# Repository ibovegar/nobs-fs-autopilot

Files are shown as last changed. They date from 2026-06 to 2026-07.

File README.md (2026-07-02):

# Nobs Autopilot

A build-it-yourself control panel for flight simulators, with **4 rotary encoders** and **8 toggle
switches** wired to an **Arduino Nano ESP32** (an older **Arduino Micro** is also supported). It
plugs in over USB and shows up as a standard game controller (HID gamepad) named **"Nobs
Autopilot"**, recognised directly by MSFS or DCS and the Nobs app, with no drivers to install.

Each encoder's turn-left, turn-right, and push are reported as 3 buttons (12 total); the 8 toggle
switches add 8 more, for **20 buttons** total.

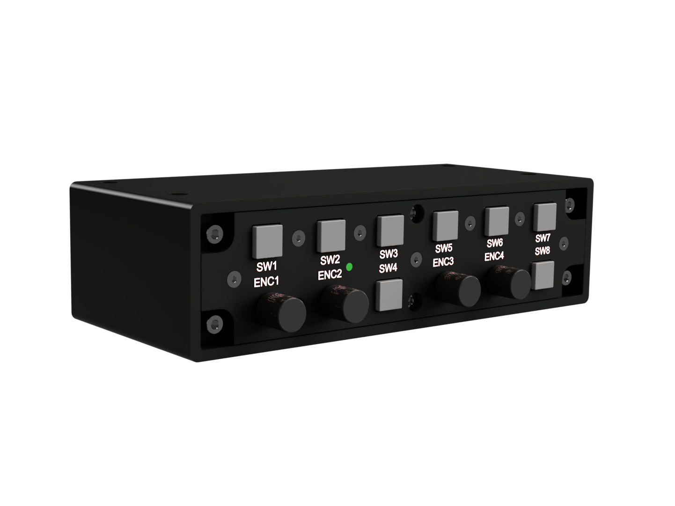
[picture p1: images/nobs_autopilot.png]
Nobs Autopilot


## Mounting

The Nobs panels are designed to mount to a 40x80 T-slot aluminium extrusion rig (e.g. a Track
Racer TR160), around the central profile assembly that holds the flight yoke or steering wheel:
**Nobs Panel** mounts to the left of the assembly, **Nobs Approach** to the right, and **Nobs
Autopilot** on top.

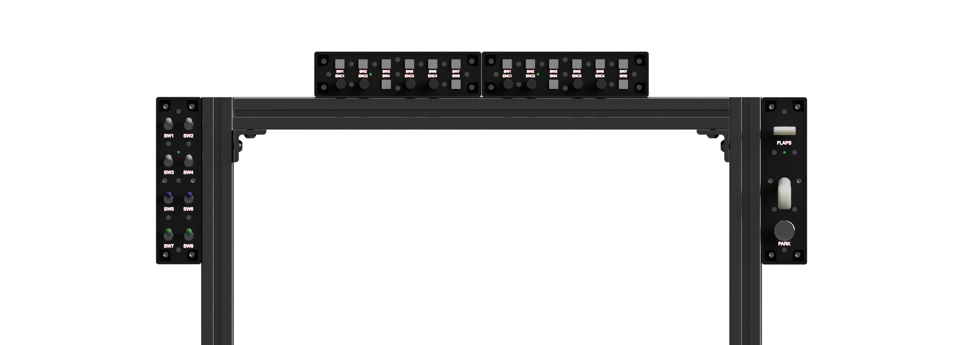
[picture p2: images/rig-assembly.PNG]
Rig assembly


## Virtual Reality (VR) Design Philosophy

Unlike traditional cockpit panels, **this project is engineered specifically for VR flight
simulator users**. Because you cannot see your physical hands while wearing a headset, this panel
discards all visual screens, LEDs, and digital displays. Instead, it focuses entirely on **tactile
memory and physical feedback**:
* **High-Tactile Feedback:** Built using premium mechanical rotary encoders with clear, distinct
  detents (clicks) and robust subminiature toggle switches that offer a sharp, reassuring snap when
  thrown.
* **Spatial Layout Optimization:** The generous spacing and deliberate physical grouping of
  components make it incredibly easy to find, identify, and operate different knobs and buttons
  purely by touch.

## Docs

- **[Build instructions](docs/build-instructions.md)**: wiring map, physical pinout reference,
  step-by-step assembly with photos, and first-time verification.
- **[Which wire goes where](docs/arduino-esp-32-wiring.md)**: the button + pin map for the Nano
  ESP32 build. For a visual reference alongside it, see the
  [wiring diagram](docs/wiring-diagram-esp32-nano.pdf).
- **[Loading the firmware](firmware/arduino_eps32_nano/README.md)**: first-time flashing and
  re-flashing, step by step.
- **[Setting the device ID & name](docs/board-identity.md)**: how the board names itself, how to
  rename it, and how to run several boxes at once.
- **[Bill of materials](docs/bill-of-materials.md)**: parts list and project cost estimate.

## Using an Arduino Micro instead of the Nano ESP32

This guide is written around the **Arduino Nano ESP32**, but the project still fully supports the
older **Arduino Micro**; it ends up as the same **"Nobs Autopilot"** device (`303A` / `80F4`) and
behaves identically in the sim, except its name/ID are fixed at compile time instead of
reconfigurable (see [docs/board-identity.md](docs/board-identity.md)). If you go with the Micro,
two things differ:

1. **Wiring pins:** use [docs/arduino-micro-wiring.md](docs/arduino-micro-wiring.md) instead of
   the Nano ESP32 pin table in the [build instructions](docs/build-instructions.md), with its own
   [wiring diagram](docs/wiring-diagram-micro.pdf).
2. **Loading the firmware:** follow
   [firmware/arduino_micro/README.md](firmware/arduino_micro/README.md) instead (it needs a
   one-time `boards.txt` edit to set the board's USB name/ID before the first upload).

Everything else is unchanged: the parts list (just swap the board), the 3D-printed enclosure, the
assembly steps, the Nobs app, and the in-sim binding.

## Nobs FS Companion App

The [**Nobs FS app**](https://github.com/ibovegar/nobs-fs-app) is the companion application for
communicating with and configuring this panel. It automatically detects the Nobs Autopilot by its
USB identity (VID `303A` / PID `80F4`), so the right device is selected even when other game
controllers are connected.

Use it to:
* **Verify wiring & test inputs:** watch every encoder rotation, encoder push, and switch register
  live as you turn or press each control, handy for confirming the build before binding anything in
  the sim.
* **Configure the encoders:** the Settings page sets each encoder's acceleration sensitivity over
  the USB serial (CDC) port. The value is persisted to the Arduino's EEPROM, so it survives power
  cycles and applies in the sim too, no re-flashing required.

See the app repository for installation and usage details: <https://github.com/ibovegar/nobs-fs-app>

## Setting the device ID & name (in brief)

The board's name and USB product ID aren't compiled in: they're stored on the board (Nano ESP32
build only), so the same firmware can be set up as any Nobs profile. Out of the box this is
**"Nobs Autopilot"** (`303A` / `80F4`). To change it, the configuration app sends a single line
over the board's serial port:

```
SET_ID:80F4:Nobs Autopilot
```

The board saves the new name + ID, replies `OK:80F4:Nobs Autopilot`, and reboots so it takes effect
(`GET_ID` reads back the current values). For multiple autopilots, give each one the next ID in the
block, e.g. `SET_ID:80F5:Nobs Autopilot 2`. Full details, including the Windows name-cache
refresh, are in **[docs/board-identity.md](docs/board-identity.md)**.

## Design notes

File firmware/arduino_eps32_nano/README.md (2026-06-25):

# Nobs Autopilot: Arduino Nano ESP32 Firmware

> **Which board do you have?** This page is for the **Arduino Nano ESP32**, the main board for
> this project. If you're using the older **Arduino Micro** instead, follow
> [the Arduino Micro guide](../arduino_micro/README.md).

This is the program (the "firmware") that runs on an **Arduino Nano ESP32** board and turns it
into a USB game controller for Microsoft Flight Simulator. Once it's loaded, the board shows up
to your PC and to the Nobs app as **"Nobs Autopilot"** with **20 buttons**:

| Buttons | What they are |
| :--- | :--- |
| 12 buttons | 4 rotary knobs (each gives: turn left, turn right, press) |
| 8 buttons | 8 toggle switches |

You don't need to understand any of that to load it; just follow the steps below. If you're
curious how it works, there's a [How it works](#how-it-works-optional-reading) section at the end.

**Files you'll use** (they're all in this folder):
- The firmware: [`arduino_eps32_nano.ino`](./arduino_eps32_nano.ino)
- A small settings file next to it: [`build_opt.h`](./build_opt.h) *(leave it where it is, it's important)*
- Which wire goes where: [`docs/arduino-esp-32-wiring.md`](../../docs/arduino-esp-32-wiring.md)

> 👍 Good news: everything needed is already in this project folder. You do **not** have to edit
> any Arduino program files. Tested with the Arduino ESP32 board package version `2.0.18-arduino.5`.

## What you need

- An **Arduino Nano ESP32** board and a USB cable.
- The **Arduino IDE** installed (the free app from arduino.cc).
- This project downloaded to your computer.

## Step 1: Add support for the board

The Arduino IDE doesn't know about the Nano ESP32 until you add it:

1. In the Arduino IDE, open **Tools → Board → Boards Manager…**
2. In the search box type **Arduino ESP32 Boards** and click **Install** on the result by *Arduino*.
   This is a big download, so give it a few minutes.
3. When it's done, go to **Tools → Board → Arduino ESP32 Boards → Arduino Nano ESP32**.

> **If the install fails** with a message like *"platform not installed"*: close the Arduino IDE,
> right-click it and choose **Run as administrator**, then try the install again. (Windows needs
> the extra permission to set up the USB drivers.)

## Step 2: Pick the right settings

In the **Tools** menu, set:

- **USB Mode** → **`Normal mode (TinyUSB)`** (this is usually the default). Don't pick "Debug
  mode (Hardware CDC)".
- **Pin Numbering** → **`By Arduino pin (default)`** so the wiring diagram matches.

That's it; no other settings to change.

## Step 3: Load the firmware onto the board

1. Open `arduino_eps32_nano.ino` (in this folder) in the Arduino IDE.
   *(Keep the `build_opt.h` file in the same folder; the IDE uses it automatically.)*
2. Plug in the board.
3. Click the **Upload** button (the round arrow, top-left).

The **first** time, this just works. 🎉 When it's done, the board reconnects as **Nobs Autopilot**
and you can use it in the app.

> The board's name and product ID aren't baked into the firmware: they're stored on the board and
> can be changed later by the configuration app (see [Changing the board's
> identity](#changing-the-boards-identity-advanced)). Out of the box it's **"Nobs Autopilot"**.

## Loading it again later (please read, it's different!)

After the firmware is on the board, the board changes its "name tag" to Nobs Autopilot. The
Arduino IDE looks for the *original* Arduino name tag when uploading, so a normal Upload will now
**fail** with a red error like:

```
No DFU capable USB device available
Failed uploading: uploading error: exit status 74
```

This is normal and expected; it just means you need to put the board into its **update mode**
first. Here's how:

1. Find the small **RESET** button on the board.
2. **Press it twice, quickly**, like a fast mouse double-click.
3. Watch the lights: the **yellow/amber light goes off**, and a **green light slowly pulses in
   and out**. That pulsing green light means the board is now waiting for an update. 👍
4. **Now click Upload** in the Arduino IDE. It will load the firmware.
5. When it finishes, **press RESET once** (a single press) to start the new firmware. The
   yellow light comes back on.

> The double-tap takes a little practice: press, then press again within about half a second.
> If the yellow light stays on, it didn't work; just try the rhythm again. You can't break the
> board by doing this.

### If the double-tap won't cooperate (optional, more advanced)

You can load the firmware from the command line instead, which avoids the timing dance. Open
**PowerShell** in the project folder and run:

```powershell
# 1) Build the firmware once (find arduino-cli.exe inside your Arduino IDE install folder):
& "<path to your Arduino IDE>\resources\app\lib\backend\resources\arduino-cli.exe" `
  compile -b arduino:esp32:nano_nora --output-dir .\out firmware\arduino_eps32_nano

# 2) Double-tap RESET so the green light is pulsing, then run:
& "$env:LOCALAPPDATA\Arduino15\packages\arduino\tools\dfu-util\0.11.0-arduino5\dfu-util.exe" `
  --device 0x2341:0x0070 -D .\out\arduino_eps32_nano.ino.bin -Q

# 3) Press RESET once to start the firmware.
```

It worked if you see `Download done.` and `Done!` at the end.

## Checking that it works

- **Windows "game controllers" tool:** press `Win`, type **Set up USB game controllers**, open
  it, select the device, click **Properties**, and wiggle your knobs/switches; you should see
  the 20 buttons light up.
- **The Nobs app:** the controller is picked automatically, and the Settings page can connect to
  it.

### Finding it in Windows Device Manager

If you go looking in **Device Manager** and can't find "Nobs Autopilot", don't worry: it's
there, just listed in a confusing way by default. The easy fix:

> In Device Manager, click the **View** menu → **Devices by container**. Now the board shows up
> as a single entry named **Nobs Autopilot**. ✅

## Changing the board's identity (advanced)

Every Nobs box needs its own **product ID (PID)** and name so MSFS keeps their button bindings
separate. This board uses vendor ID `303A` and defaults to PID `80F4` / name **"Nobs Autopilot"**,
but those aren't compiled in. They're stored on the board and can be changed without re-flashing,
which is how the same firmware can be set up as any Nobs profile.

The configuration app does this for you over the board's COM port by sending a single line:

```
SET_ID:80F4:Nobs Autopilot
```

(`80F4` is the PID in hex; the text after it is the name.) The board saves the new values to its
internal memory, replies `OK:80F4:Nobs Autopilot`, and then **reboots itself** so the new identity
takes effect. Send `GET_ID` to read back what's currently stored (it replies `ID:80F4:Nobs Autopilot`).

Each product owns a **block of PIDs** so you can run several of the same type: each physical unit
takes the next PID in the block and a numbered name (module 1 keeps the bare name and the block's
first PID, its default):

| Profile | Vendor ID | PID block | Module 1 command |
| :--- | :--- | :--- | :--- |
| Nobs Panel | `303A` | `80F0`–`80F3` | `SET_ID:80F0:Nobs Panel` |
| Nobs Autopilot | `303A` | `80F4`–`80F7` | `SET_ID:80F4:Nobs Autopilot` |
| Nobs Approach | `303A` | `80F8`–`80FB` | `SET_ID:80F8:Nobs Approach` |

So a second autopilot would be `SET_ID:80F5:Nobs Autopilot 2`, a third `SET_ID:80F6:Nobs Autopilot 3`,
and so on.

> After changing the name, if Windows still shows the old one in **Game Controllers** or MSFS,
> force a refresh: in **Device Manager → Human Interface Devices**, right-click the controller →
> **Uninstall device**, then unplug the USB cable, wait ~2 seconds, and plug it back in. Windows
> re-reads the name fresh.

(In the normal view, one USB gadget like this gets split into a few separate generic-looking
entries (a "game controller", a "COM port", and a "USB Composite Device"), which is why it can
look like it's missing.)

## If something goes wrong

| What you see | What it means | What to do |
| :--- | :--- | :--- |
| *"Platform 'arduino:esp32' not found"* | The board support isn't installed | Do Step 1 again. On Windows, run the IDE **as administrator** if it fails partway. |
| Upload fails: *"No DFU capable USB device available"* or *"exit status 74"* | The board isn't in update mode | Double-tap RESET (wait for the pulsing green light), **then** Upload. See [Loading it again later](#loading-it-again-later-please-read-its-different). |
| Double-tap doesn't seem to do anything | Tricky timing, or you saw the normal 1-second light show at startup | You're in update mode only when the **yellow light is OFF** and the **green light keeps pulsing**. Keep trying the double-press. |
| The app or Windows shows it as **"Unknown device"** | Windows remembered an old, blank name | In Device Manager: **View → Show hidden devices**, right-click the board → **Uninstall device**, then unplug and replug it. |
| A long list of red *"No such file or directory"* errors when compiling | Someone added comments to `build_opt.h` | The `build_opt.h` file must contain **only** the settings line, no `//` comment lines. |

## Things that look wrong but are totally fine

- **A yellow light on the board stays on.** That's normal here: one of the knob wires shares the
  board's built-in LED pin, so the light is on whenever the firmware runs. If it bothers you, you
  can move that one wire to pin **D2** or **D4** and update the firmware + wiring diagram to match.

## How it works (optional reading)

You can skip this; it's just for the curious or for anyone maintaining the project.

### Why uploading needs the extra steps

A USB device tells your PC who it is using two ID numbers (called **VID** and **PID**) plus a
name. This board uses vendor ID `303A` and, by default, PID `80F4` / "Nobs Autopilot" so the Nobs
app recognises it. The PID and name aren't compiled in: the firmware reads them from the board's
internal memory at startup, which is what lets the [configuration
app](#changing-the-boards-identity-advanced) reassign the board to a different Nobs profile.

The tricky part: the Nano ESP32 normally locks in its ID numbers the instant it powers on,
*before* our firmware gets a chance to run, and it also hard-codes the "wrong" ID. So we use a
tiny helper file, **`build_opt.h`**, that sits next to the firmware. The Arduino IDE
automatically applies the settings in that file when it builds, which tells the board *not* to
start USB at power-on. That gives our firmware the opening it needs to read the stored ID/name
and set the right identity, buttons, and serial port itself, the moment it starts. (There's also
a built-in safety check that refuses to build if `build_opt.h` ever goes missing, so the board
can never quietly get the wrong ID.)

Because the board now reports the *custom* ID, the Arduino IDE's normal "auto-restart for
upload" can't find it, which is exactly why re-uploads need the manual double-tap into update
mode.

### What the firmware actually does

- Presents itself as a 20-button game controller (no joysticks/axes).
- Reads the 4 rotary knobs with proper quadrature decoding, and turns each "click" of the knob
  into a quick button press so even fast spinning is counted correctly in MSFS. Each knob also
  has adjustable acceleration (turn faster = bigger jumps), saved on the board.
- Provides a serial port so the Nobs app's Settings page can tweak that acceleration, and so the
  configuration app can change the board's USB ID/name (see [Changing the board's
  identity](#changing-the-boards-identity-advanced)).
- Reads the 8 switches as plain buttons.

The exact pin-to-wire mapping is in the [wiring diagram](../../docs/arduino-esp-32-wiring.md).

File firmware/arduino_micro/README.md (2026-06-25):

# Nobs Autopilot: Arduino Micro Firmware

This is the program (the "firmware") that runs on an **Arduino Micro** board and turns it into a
USB game controller for your flight sim. Once it's loaded, the board shows up to your PC and to
the Nobs app as **"Nobs Autopilot"** with 20 buttons (4 knobs + 8 switches).

> **Which board do you have?** This page is for the **Arduino Micro**, an alternative to the
> project's main board. If you're using the **Arduino Nano ESP32**, follow
> [the Nano ESP32 guide](../arduino_eps32_nano/README.md) instead. Note: only the Nano ESP32 build
> can have its name/ID changed later by the configuration app. On the Micro the USB ID is fixed
> when you build it (set in Step 1 below).

For the board to show up as "Nobs Autopilot" (and be picked up automatically by the Nobs app),
it needs to report a specific **USB ID**: two numbers the PC uses to recognise it (`303A` and
`80F4`). There's a one-time setup to make that happen, then loading the firmware is easy.

## Step 1: One-time setup to give the board its name

This step tells the Arduino IDE to build the firmware with the right name and USB ID. You only
have to do this **once** on your computer.

1. **Close the Arduino IDE completely.**
2. Open File Explorer, click the address bar, paste this in, and press Enter:
   ```
   %LOCALAPPDATA%\Arduino15\packages\arduino\hardware\avr\
   ```
3. Open the folder you see there (a version number, e.g. `1.8.6`).
4. Open the file **`boards.txt`** with Notepad.
5. Press `Ctrl+F`, search for **`micro.name`** (it's around line 290), and replace those few
   lines with this:
   ```
   micro.name=Nobs Autopilot
   micro.build.vid=0x303A
   micro.build.pid=0x80F4
   micro.build.usb_product="Nobs Autopilot"
   ```
6. **Save** the file and reopen the Arduino IDE.

> This only changes your own computer's Arduino setup. It doesn't change the project files, and
> anyone you give a finished, already-flashed board to doesn't need to do any of this.

## Step 2: Load the firmware

1. Open `arduino_micro.ino` (in this folder) in the Arduino IDE.
2. Go to **Tools → Board** and select **Nobs Autopilot** (that's the Arduino Micro; it shows the
   new name now because of Step 1).
3. Plug in the board and click **Upload** (the round arrow).

That's it.

## Check that it worked

Once connected, the board should introduce itself to your PC as:

```
Nobs Autopilot (Vendor: 303a Product: 80f4)
```

The Nobs app looks for exactly that USB ID (`303a` / `80f4`), so it automatically picks the right
controller even if you have other game controllers plugged in.

> **Seeing a generic name instead?** Open Windows **Device Manager**, turn on **View → Show
> hidden devices**, right-click any old/stale listing for the board and **Uninstall device**,
> then unplug and replug it so Windows reads the new name fresh.

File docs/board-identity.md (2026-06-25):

# How the Board Names Itself (and How to Rename It)

This page explains, in plain language, how a Nobs board tells your PC who it is, and how you can
change that without re-installing the firmware. You don't need to understand any of this to use the
autopilot; it's here for the curious and for anyone setting up more than one box.

> **Applies to the Arduino Nano ESP32 build.** On the older **Arduino Micro** build the ID and name
> are fixed when you compile the firmware (set in its
> [README](../firmware/arduino_micro/README.md)) and can't be changed afterwards. Everything below,
> including renaming on the fly and running several of the same type, is a Nano ESP32 feature.

## The short version

- Every Nobs box appears to your PC as a USB game controller with a **name** (like "Nobs Autopilot")
  and an **ID number** (called a *Product ID*, or **PID**).
- That name and ID are **not baked into the firmware**. The board remembers them in its own memory,
  so the *same* firmware can be set up as a panel, an autopilot, or an approach box.
- Out of the box, this board is **"Nobs Autopilot"**. You can change it later with the configuration
  app, no re-flashing needed.

## Why each box needs its own name and ID

If you own more than one Nobs box, this matters. Microsoft Flight Simulator keeps a separate set of
button bindings for each controller, but it tells controllers apart by their **ID number**.

If two boxes shared the same ID, the simulator would treat them as the same device and **mix up
their button assignments**. Giving each box its own ID (and a clear name) keeps their controls
neatly separated, so plugging in a second or third box never disturbs the first.

Here are the standard profiles. Each product owns a small **block of IDs** so you can have several
of the same type (see below):

| If the box is a… | It should be named… | ID block |
| :--- | :--- | :--- |
| Panel | Nobs Panel | `80F0`–`80F3` |
| Autopilot | Nobs Autopilot | `80F4`–`80F7` |
| Approach | Nobs Approach | `80F8`–`80FB` |

(They all share the same *vendor* ID, `303A`; that part never changes.)

## Running several of the same type

You can use more than one of the same module (say two autopilots) at the same time. The catch is
they must **not** look identical to the PC, or the simulator mixes up their bindings. So each one
gets its own ID and name from its product's block:

| | Name | ID |
| :-- | :-- | :-- |
| 1st autopilot | Nobs Autopilot | `80F4` |
| 2nd autopilot | Nobs Autopilot 2 | `80F5` |
| 3rd autopilot | Nobs Autopilot 3 | `80F6` |

The first one keeps the plain name and the block's first ID (its out-of-box default). For each
extra one, give it the next ID and a numbered name with the rename step below, e.g. send
`SET_ID:80F5:Nobs Autopilot 2` to the second autopilot. In the Nobs app, open **Devices** and press
**+** on that product to start tracking the extra module. The simulator then sees "Nobs Autopilot"
and "Nobs Autopilot 2" as two separate controllers with independent bindings.

## How to rename a board

The configuration app does this for you. Behind the scenes it just sends the board one short line of
text over its connection, for example:

```
SET_ID:80F4:Nobs Autopilot
```

That reads as: *"Set your ID to `80F4` and your name to `Nobs Autopilot`."* The board then:

1. **Saves** the new name and ID into its own memory.
2. **Confirms** it received them.
3. **Restarts itself**, then comes back wearing the new name.

That restart is normal and only takes a second. The reason it's needed: a board can only announce
its identity to the PC at the moment it powers on, so it has to reboot for a new name to take effect.

> 💡 To check what a board is currently called, the app can ask it with `GET_ID`, and the board
> replies with its stored name and ID.

## If Windows still shows the old name

Windows likes to remember names, so occasionally after a rename it'll keep showing the **old** one
in its game-controller list or in the simulator. If that happens, nudge it to take a fresh look:

1. Leave the board plugged in.
2. Right-click the **Start** button → open **Device Manager**.
3. Open the **Human Interface Devices** group.
4. Right-click your controller → **Uninstall device**.
5. Unplug the USB cable, wait a couple of seconds, and plug it back in.

Windows will then read the board's name again from scratch and show the updated one.

## Related pages

- [Which wire goes where](./arduino-esp-32-wiring.md): the button and pin map.
- [Loading the firmware](../firmware/arduino_eps32_nano/README.md): step-by-step setup, including
  the more technical details of how the identity is stored.

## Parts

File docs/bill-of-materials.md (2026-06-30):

# Bill of Materials (Shopping List)

This is the full shopping list for building one Nobs Autopilot panel: every part you need, from
the electronics to the screws. The tables below group the parts by type. The "Manufacturer /
Part Number" column lists the exact parts we used, so you can search for them or find equivalents.

A few friendly notes before you start buying:

- **Exact parts aren't mandatory.** The encoders, switches, and Arduino can be swapped for similar
  parts you like or already have. The part numbers here are just what's known to work.
- **Item 1.1 below is the Arduino Nano ESP32, the main board for this project.** You can use an
  older **Arduino Micro** instead; the firmware supports both. See the
  [firmware guides](../firmware/arduino_micro/README.md).
- **The enclosure parts (section 3) are 3D printed**: you print them yourself from the files in
  the `models/` folder, or have a print service make them.
- Quantities are for **one** panel.

## Core Electronics & Switches

| Item # | Qty | Component Description | Manufacturer / Part Number | Purpose / Application |
| :--- | :--- | :--- | :--- | :--- |
| **1.1** | 1 | Arduino Nano ESP32 (with headers) | Arduino / ABX00083 | Main microcontroller (ESP32-S3, USB HID, VID 0x303A / PID 0x80F4); or substitute an Arduino Micro (Arduino / A000053) |
| **1.2** | 4 | High-Reliability Mechanical Rotary Encoder | Bourns / PEC11H-4020F-S0016 | Multi-turn cockpit adjustments (HDG, ALT, V/S, SPD) |
| **1.3** | 8 | Subminiature SPDT Momentary Toggle Switch | E-Switch / 700SP7B10M2REH | Panel engagement buttons (SW1–SW8) |
| **1.4** | 1 | Stripboard Prototype Board | BusBoard Prototype Systems / StripBoard-1 | Main sub-assembly chassis carrier board |
| **1.5** | 2 | Female 2.54 mm Pin Header, 26 positions | — | Sockets soldered to the stripboard to seat the Arduino board (Nano ESP32 or Micro) |
| **1.6** | 8 | Fixed Terminal Block (2.54 mm Pitch) | GCT / TBC05-06-1-G-G | Clean screw-down wiring for switches and encoders |
| **1.7** | 1 | 3 mm Green Diffused LED | Lumex / SSL-LX30FT4GD | Power/status indicator |
| **1.8** | 1 | 120 Ω Metal Film Resistor, 1/4 W, ±1% | KOA Speer / MFS1/4DCT52R1200F | Current-limiting resistor for the indicator LED |

## Knobs, Caps, Connectors & Wiring

| Item # | Qty | Component Description | Specifications / Notes | Purpose / Application |
| :--- | :--- | :--- | :--- | :--- |
| **2.1** | 4 | Rotary Encoder Knob, 14 × 14.5 mm | Same Sky / SAK-023 | Physical interface dials for the 4 rotary encoders |
| **2.2** | 8 | Button Cap | C&K / 798209000 | Caps for the 700-series momentary switches |
| **2.3** | 1 | USB-C to USB-A Cable | 1.5 m to 2 m, data-sync capable | Connects the Arduino Nano ESP32 to your PC flight simulator setup (use USB Micro-B instead if building with the Arduino Micro) |
| **2.4** | 1 | 24 AWG Solid Core Hook-Up Wire Kit | Multi-color pack (black, red, blue, yellow) | Internal point-to-point wiring (signals and ground loops) |
| **2.5** | 1 | Heat Shrink Tubing Assortment Pack | 1.5 mm to 3.5 mm diameters | Insulates soldered connections on the encoder and switch lugs |

## Structural & Enclosure Hardware

| Item # | Qty | Component Description | Specifications / Notes | Purpose / Application |
| :--- | :--- | :--- | :--- | :--- |
| **3.1** | 1 | Enclosure Top | 3D Printed (PLA/PETG) | Main upper housing body shell |
| **3.2** | 1 | Enclosure Bottom | 3D Printed (PLA/PETG) | Main lower housing base structure |
| **3.3** | 1 | Mounting Plate | 3D Printed (PLA/PETG) | Interface bracket to attach the panel to your desk/rig |
| **3.4** | 1 | Front Plate | 3D Printed (PLA/PETG) | Visual faceplate holding switches and text labels |
| **3.5** | 13 | M3 Heat-Set Insert | Brass, press-fit | Threaded anchors moulded into the 3D-printed parts |
| **3.6** | 10 | M4 Heat-Set Insert | Brass, press-fit | Threaded anchors moulded into the 3D-printed parts |
| **3.7** | 9 | M3 × 10 mm Countersunk Screw | Flat head machine screws | Fastens the front plate flat against the enclosure frame |
| **3.8** | 4 | M3 × 6 mm Pan-Head Screw | Rounded button head | Fastens the internal circuit board assembly to its mounts |
| **3.9** | 6 | M4 × 6 mm Socket-Head Screw | Hex drive cap screws | Fastens the mounting plate interface to the enclosure body |
| **3.10** | 4 | M4 × 26 mm Socket-Head Screw | Hex drive long cap screws | Clamps the enclosure top and bottom halves together |

## Tools Recommended for Assembly (Not in BOM Cost)
* **Soldering Iron & Lead-Free Rosin-Core Solder:** Essential for attaching wires to the E-Switch gold terminals and Bourns pins.
* **Wire Strippers & Flush Cutters:** For clean trimming and prepping of your 24 AWG signal cables.
* **Soldering Iron / Insert Tool for Heat-Set Inserts:** For pressing the brass inserts squarely into the 3D-printed parts.
* **Multimeter:** Crucial for testing continuity and checking for short circuits across your common ground loops before plugging into USB power.

## Project Costs

Rough cost estimate for a single panel, in USD. These are ballpark figures only, actual prices vary significantly by supplier, region, and quantity, and **exclude shipping and taxes**. Several items (wire, heat-shrink, screws, inserts) are sold in multi-build packs, so the per-build cost is lower if you build more than one or already have them on hand.

| Category | Items | Estimated Cost |
| :--- | :--- | ---: |
| Microcontroller | Arduino Nano ESP32 (genuine; clones are cheaper) | $20 – $28 |
| Rotary encoders | 4 × Bourns PEC11H | $10 – $15 |
| Switches | 8 × E-Switch 700-series momentary | $25 – $35 |
| Board & wiring | Stripboard, pin headers, 8 × terminal blocks | $12 – $18 |
| Indicator LED | LED + current-limiting resistor | $1 – $2 |
| Knobs & caps | 4 × encoder knobs, 8 × button caps | $15 – $25 |
| Connectors & consumables | USB cable, hook-up wire kit, heat-shrink | $20 – $25 |
| Fasteners | Heat-set inserts, M3/M4 screws | $10 – $18 |
| Enclosure (3D printed) | Filament for top, bottom, mounting plate, front plate | $5 – $15 |
| **Total** | | **≈ $120 – $180** |

> **Notes:**
> * The **enclosure** assumes you print the parts yourself (filament cost only). Ordering them from a print service will add roughly $30 – $80.
> * Choosing an **Arduino Nano ESP32 clone** instead of a genuine board can cut $10 – $15 off the total.
> * Bulk/pack purchasing of consumables and fasteners spreads their cost across multiple builds, lowering the effective per-panel total.
</content>

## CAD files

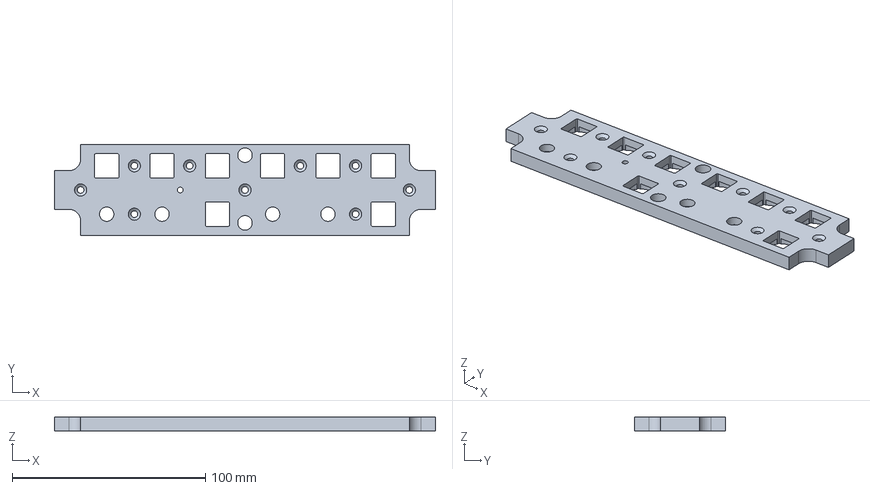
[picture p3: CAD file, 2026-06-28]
models/nobs_autopilot_frontpanel.step
197.0 x 47.0 x 7.00 mm

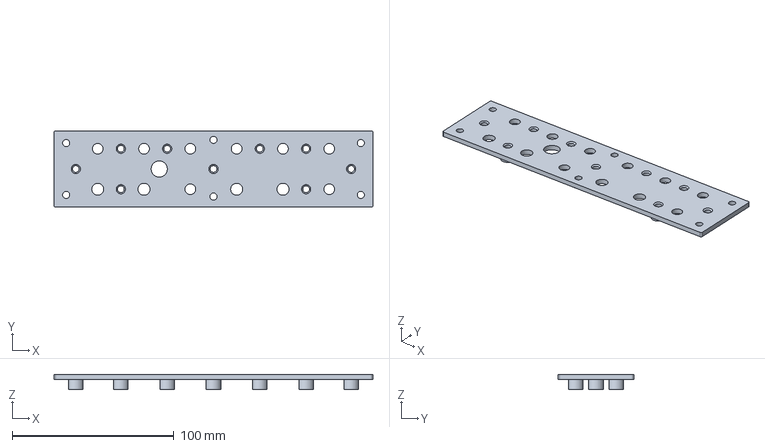
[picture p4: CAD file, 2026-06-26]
models/nobs_autopilot_mounting_plate.step
197.0 x 47.0 x 9.00 mm

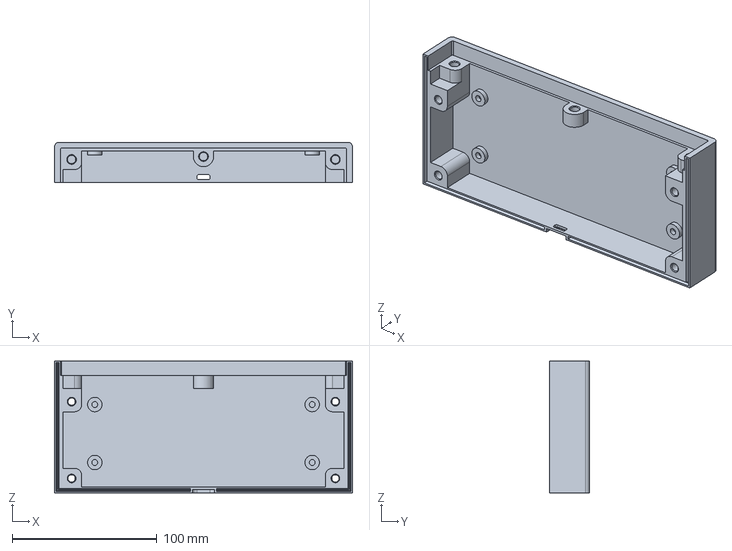
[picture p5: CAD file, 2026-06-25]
models/enclosure_top.step
205.6 x 27.8 x 91.0 mm

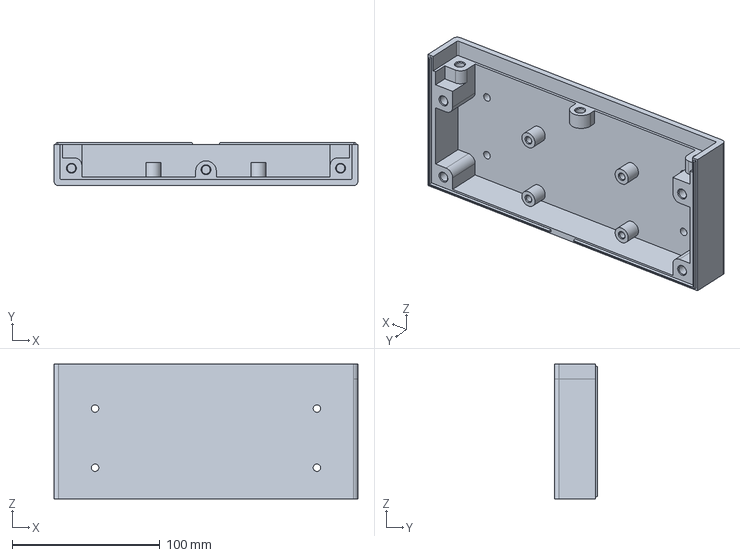
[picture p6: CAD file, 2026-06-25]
models/enclosure_bottom.step
205.6 x 29.3 x 91.0 mm

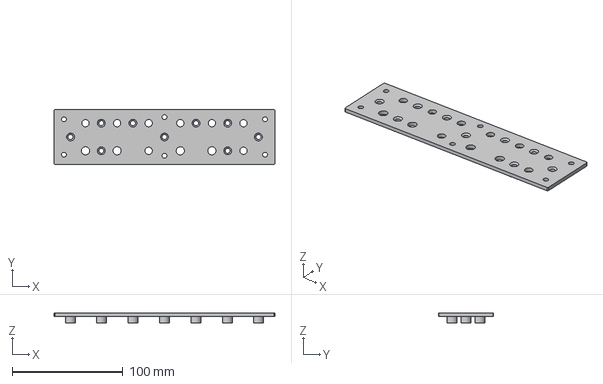
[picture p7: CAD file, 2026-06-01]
models/Mounting_plate.step
200.0 x 50.0 x 9.00 mm

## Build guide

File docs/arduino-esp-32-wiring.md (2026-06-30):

# Wiring Map: Which Wire Goes Where

This table tells you which pin on the board each wire connects to, for the **Arduino Nano ESP32**
(the main board for this project). Building with the older **Arduino Micro** instead? Use
[arduino-micro-wiring.md](arduino-micro-wiring.md) instead.

**How to read a row:** find the part (e.g. "Encoder 1"), look at what it's connecting ("Phase A
Terminal"), then run a wire from that terminal to the pin listed in the board's column. Pin
names like `D13` or `A0` are printed on the board itself. Every part also connects to **GND**
(ground), see the last row.

The "Virtual HID Button" column is just for reference: it's the button number the sim sees when
you use that control. You don't wire anything for it.

> 💡 Each control has one wire to its signal pin (from this table) and one wire to **GND**. No
> resistors or extra parts needed; the firmware handles that.
>
> For a visual reference alongside this table, see the [wiring diagram](wiring-diagram-esp32-nano.pdf).

| Component Group | Component Label | Hardware Connection | Arduino Nano ESP32 Pin | Virtual HID Button | Action Type |
| :--- | :--- | :--- | :--- | :--- | :--- |
| **Encoder 1** | Encoder 1 | Phase A Terminal | **D13** | Button 1 | CW Pulse |
| | Encoder 1 | Phase B Terminal | **A0** | Button 2 | CCW Pulse |
| | Encoder 1 | Switch Terminal 1 | **A1** | Button 3 | Push |
| **Encoder 2** | Encoder 2 | Phase A Terminal | **A2** | Button 4 | CW Pulse |
| | Encoder 2 | Phase B Terminal | **A3** | Button 5 | CCW Pulse |
| | Encoder 2 | Switch Terminal 1 | **A4** | Button 6 | Push |
| **Encoder 3** | Encoder 3 | Phase A Terminal | **A5** | Button 7 | CW Pulse |
| | Encoder 3 | Phase B Terminal | **A6** | Button 8 | CCW Pulse |
| | Encoder 3 | Switch Terminal 1 | **A7** | Button 9 | Push |
| **Encoder 4** | Encoder 4 | Phase A Terminal | **D0** | Button 10 | CW Pulse |
| | Encoder 4 | Phase B Terminal | **D1** | Button 11 | CCW Pulse |
| | Encoder 4 | Switch Terminal 1 | **D3** | Button 12 | Push |
| **Switches** | Switch 1 (SW1) | Terminal 2 (N.O.) | **D12** | Button 13 | Push |
| | Switch 2 (SW2) | Terminal 2 (N.O.) | **D11** | Button 14 | Push |
| | Switch 3 (SW3) | Terminal 2 (N.O.) | **D10** | Button 15 | Push |
| | Switch 4 (SW4) | Terminal 2 (N.O.) | **D9** | Button 16 | Push |
| | Switch 5 (SW5) | Terminal 2 (N.O.) | **D8** | Button 17 | Push |
| | Switch 6 (SW6) | Terminal 2 (N.O.) | **D7** | Button 18 | Push |
| | Switch 7 (SW7) | Terminal 2 (N.O.) | **D6** | Button 19 | Push |
| | Switch 8 (SW8) | Terminal 2 (N.O.) | **D5** | Button 20 | Push |
| **Ground Loop** | All Components | Common / GND Terminals | **GND** | *None* | System Ground |
| **Status LED** | Status LED | Anode, via 120 Ω resistor | **D4** | *None* | Boot/Connect Status |
| | Status LED | Cathode | **GND** | *None* | Boot/Connect Status |

> 💡 **Status LED:** wired with a 120 Ω current-limiting resistor from **D4** to **GND**. It blinks
> while the board is booting/waiting for USB enumeration, and lights steady once the host PC has
> enumerated it.

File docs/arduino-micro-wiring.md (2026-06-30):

# Wiring Map: Which Wire Goes Where

This table tells you which pin on the board each wire connects to, for the **Arduino Micro** (the
older, alternative board; the main build uses the **Arduino Nano ESP32**; see
[arduino-esp-32-wiring.md](arduino-esp-32-wiring.md)).

**How to read a row:** find the part (e.g. "Encoder 1"), look at what it's connecting ("Phase A
Terminal"), then run a wire from that terminal to the pin listed in the board's column. Pin
names like `D3` or `A0` are printed on the board itself. Every part also connects to **GND**
(ground), see the last row.

The "Virtual HID Button" column is just for reference: it's the button number the sim sees when
you use that control. You don't wire anything for it.

> 💡 Each control has one wire to its signal pin (from this table) and one wire to **GND**. No
> resistors or extra parts needed; the firmware handles that.
>
> For a visual reference alongside this table, see the [wiring diagram](wiring-diagram-micro.pdf).

| Component Group | Component Label | Hardware Connection | Arduino Micro Pin | Virtual HID Button | Action Type |
| :--- | :--- | :--- | :--- | :--- | :--- |
| **Encoder 1** | Encoder 1 | Phase A Terminal | **A0** | Button 1 | CW Pulse |
| | Encoder 1 | Phase B Terminal | **A1** | Button 2 | CCW Pulse |
| | Encoder 1 | Switch Terminal 1 | **A2** | Button 3 | Push |
| **Encoder 2** | Encoder 2 | Phase A Terminal | **A3** | Button 4 | CW Pulse |
| | Encoder 2 | Phase B Terminal | **A4** | Button 5 | CCW Pulse |
| | Encoder 2 | Switch Terminal 1 | **A5** | Button 6 | Push |
| **Encoder 3** | Encoder 3 | Phase A Terminal | **D3** | Button 7 | CW Pulse |
| | Encoder 3 | Phase B Terminal | **D2** | Button 8 | CCW Pulse |
| | Encoder 3 | Switch Terminal 1 | **D4** | Button 9 | Push |
| **Encoder 4** | Encoder 4 | Phase A Terminal | **D0 (RX)** | Button 10 | CW Pulse |
| | Encoder 4 | Phase B Terminal | **D1 (TX)** | Button 11 | CCW Pulse |
| | Encoder 4 | Switch Terminal 1 | **D16 (MOSI)** | Button 12 | Push |
| **Switches** | Switch 1 (SW1) | Terminal 2 (N.O.) | **D12** | Button 13 | Push |
| | Switch 2 (SW2) | Terminal 2 (N.O.) | **D11** | Button 14 | Push |
| | Switch 3 (SW3) | Terminal 2 (N.O.) | **D10** | Button 15 | Push |
| | Switch 4 (SW4) | Terminal 2 (N.O.) | **D9** | Button 16 | Push |
| | Switch 5 (SW5) | Terminal 2 (N.O.) | **D8** | Button 17 | Push |
| | Switch 6 (SW6) | Terminal 2 (N.O.) | **D7** | Button 18 | Push |
| | Switch 7 (SW7) | Terminal 2 (N.O.) | **D6** | Button 19 | Push |
| | Switch 8 (SW8) | Terminal 2 (N.O.) | **D5** | Button 20 | Push |
| **Ground Loop** | All Components | Common / GND Terminals | **GND** | *None* | System Ground |

> **Pin notes:**
> * Encoder 4's push switch sits on **D16 (MOSI)** rather than the adjacent D17, because D17 drives the on-board RX LED, which holds the line low and would register a phantom press.
> * Encoder 4's Phase A/B share the **D0/D1** UART pins. These stay free for digital I/O because the Arduino Micro talks to the host over native USB CDC, not the hardware UART.

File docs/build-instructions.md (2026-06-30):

# Nobs Autopilot: Build Instructions

These are the hands-on build steps for the Nobs Autopilot panel: how to wire it,
how to assemble it, and how to verify it before binding in the sim. For the project
overview, firmware loading, and the in-sim control mapping, see the
[main README](../README.md). For the parts list and cost estimate, see
[bill-of-materials.md](bill-of-materials.md).

The wiring table and steps below show the **Arduino Nano ESP32** build, the main board for this
project. If you're using the older Arduino Micro instead, use the pin column for it in
[arduino-micro-wiring.md](arduino-micro-wiring.md).

## Hardware Connection Scheme

This is the wiring map: each control has one wire to a numbered pin on the Arduino, and one wire
to **GND** (ground). That's all: you don't need any resistors or extra parts, because the
firmware takes care of that for you.

The table below is for the **Arduino Nano ESP32**. Using the older **Arduino Micro**? The pins are
different; see [arduino-micro-wiring.md](arduino-micro-wiring.md) for its column.

> For a visual reference alongside this table, see the [wiring diagram](wiring-diagram-esp32-nano.pdf) (or the [Arduino Micro wiring diagram](wiring-diagram-micro.pdf) if you're using that board).

| Component Group | Component Label | Hardware Connection | Arduino Nano ESP32 Pin | Virtual HID Button | Action Type |
| :--- | :--- | :--- | :--- | :--- | :--- |
| **Encoder 1** | Encoder 1 | Phase A Terminal | **D13** | Button 1 | CW Pulse |
| | Encoder 1 | Phase B Terminal | **A0** | Button 2 | CCW Pulse |
| | Encoder 1 | Switch Terminal 1 | **A1** | Button 3 | Push |
| **Encoder 2** | Encoder 2 | Phase A Terminal | **A2** | Button 4 | CW Pulse |
| | Encoder 2 | Phase B Terminal | **A3** | Button 5 | CCW Pulse |
| | Encoder 2 | Switch Terminal 1 | **A4** | Button 6 | Push |
| **Encoder 3** | Encoder 3 | Phase A Terminal | **A5** | Button 7 | CW Pulse |
| | Encoder 3 | Phase B Terminal | **A6** | Button 8 | CCW Pulse |
| | Encoder 3 | Switch Terminal 1 | **A7** | Button 9 | Push |
| **Encoder 4** | Encoder 4 | Phase A Terminal | **D0** | Button 10 | CW Pulse |
| | Encoder 4 | Phase B Terminal | **D1** | Button 11 | CCW Pulse |
| | Encoder 4 | Switch Terminal 1 | **D3** | Button 12 | Push |
| **Switches** | Switch 1 (SW1) | Terminal 2 (N.O.) | **D12** | Button 13 | Push |
| | Switch 2 (SW2) | Terminal 2 (N.O.) | **D11** | Button 14 | Push |
| | Switch 3 (SW3) | Terminal 2 (N.O.) | **D10** | Button 15 | Push |
| | Switch 4 (SW4) | Terminal 2 (N.O.) | **D9** | Button 16 | Push |
| | Switch 5 (SW5) | Terminal 2 (N.O.) | **D8** | Button 17 | Push |
| | Switch 6 (SW6) | Terminal 2 (N.O.) | **D7** | Button 18 | Push |
| | Switch 7 (SW7) | Terminal 2 (N.O.) | **D6** | Button 19 | Push |
| | Switch 8 (SW8) | Terminal 2 (N.O.) | **D5** | Button 20 | Push |
| **Ground Loop** | All Components | Common / GND Terminals | **GND** | *None* | System Ground |

> **Pin notes:**
> * Encoder 1's Phase A wire is on **D13**, which doubles as the board's built-in LED pin, which is why the onboard yellow LED stays lit whenever the firmware is running. It's harmless; move that wire to D2 or D4 (and update the firmware to match) if it bothers you.

## Physical Pinout Reference

### Rotary Encoder Layout
Viewed from the bottom of the housing with the three closely spaced pins facing downward:

```text
       [ Top: Encoder Shaft Side ]

         (A)      (C/GND)     (B)     <-- 3 Pins (Rotation Control)

          |          |         |

        (SW1)                (SW2)    <-- 2 Pins (Push Button Switch)
```
* **Wiring Rotation:** Connect `A` and `B` to their designated Arduino pins. Connect the middle pin `C/GND` to your master ground loop.
* **Wiring Button:** Connect `SW1` to its designated Arduino push-button pin. Connect `SW2` directly to your master ground loop.

### Momentary Switch Toggle Layout
Viewed from the rear showing three vertically aligned gold terminals:

```text
         [ ]  Terminal 1 (Common - C)             --> Connect to Master Ground Loop
         [ ]  Terminal 2 (Normally Open - N.O.)   --> Connect to Arduino Pin
         [ ]  Terminal 3 (Normally Closed - N.C.) --> LEAVE DISCONNECTED
```

## Assembly Instructions

Here's how the panel goes together, in order, with a photo of the real build at each stage.
There's soldering involved, so take your time and work in a well-lit, ventilated spot. Don't
rush: it's much easier to get each joint right the first time than to fix it later.

The build happens in four stages: (1) build the little breakout board the Arduino sits on, (2)
wire up the switches and knobs, (3) mount everything to the front plate, and (4) close it all up
in the case.

### Phase 1: Breakout Board Assembly

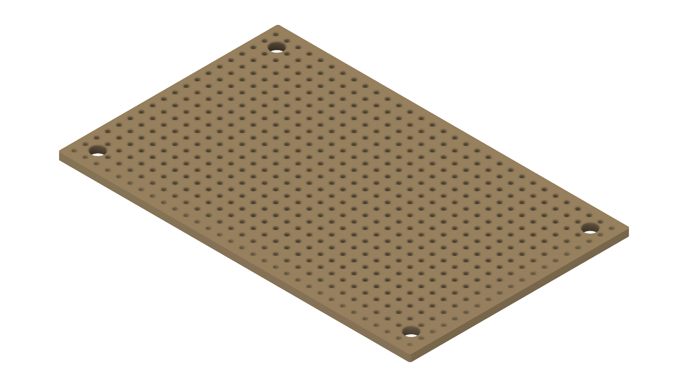
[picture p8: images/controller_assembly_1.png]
Bare stripboard


* **Fit Headers:** Position female socket headers onto the stripboard to seat your Arduino board
  (Nano ESP32 or Micro; the same stripboard layout fits either) and solder them from underneath.

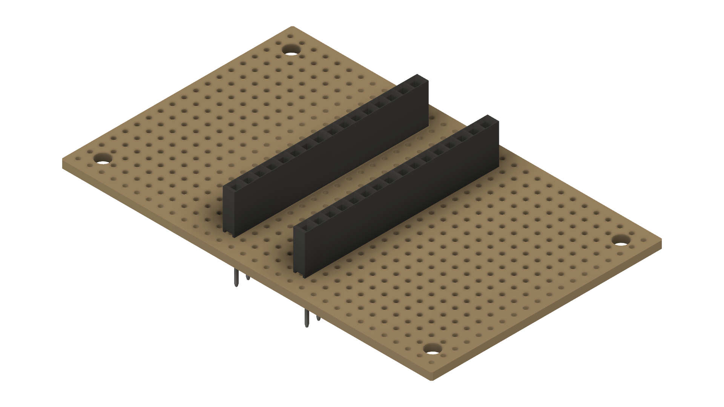
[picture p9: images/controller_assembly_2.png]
Female socket headers fitted to the stripboard
  
* **Mount Terminal Blocks:** Place the screw terminal blocks flanking the socket headers on the
  stripboard and solder them into place.

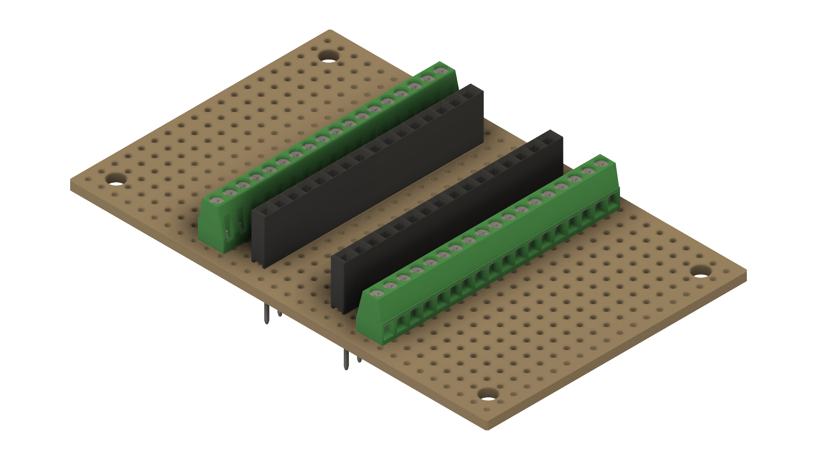
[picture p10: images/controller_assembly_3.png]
Terminal blocks mounted alongside the headers
  
* **Bridge Traces:** Ensure the copper traces on the stripboard securely connect each header pin
  footprint directly to its corresponding terminal block clamping slot.
* **Isolate Rails:** Use a track cutter or utility knife to score and break any copper traces
  running between opposing header pin rows to prevent short circuits.
* **Seat the Microcontroller:** Carefully align your Arduino board's pins with the female headers
  on the stripboard. Press down uniformly until fully seated.

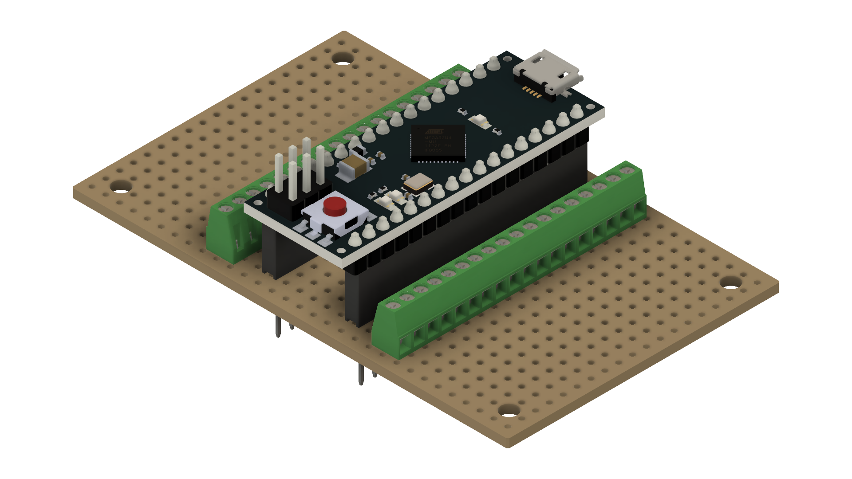
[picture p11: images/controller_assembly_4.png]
Arduino board seated in the finished breakout board
  

### Phase 2: Component Pre-Wiring
* **Prep Signal Lines:** Cut hook-up wire into 15–20 cm lengths. Strip 3 mm of insulation off both ends of each wire run.
* **Wire the Switches:** Slide heat shrink tubing over your wires. Solder a signal wire to the N.O. terminal and a ground wire to the common terminal of each switch. Leave the N.C. terminal disconnected. Shrink the tubing over the joints.
* **Wire the Encoders:** Solder independent signal lines to Phase A and Phase B. Solder a third line to one push-switch terminal, and bridge the middle ground terminal to the second push-switch terminal with a shared wire.
* **Construct Ground Harness:** Tie the ground wires from all encoders and switches together into a unified, clean common ground harness to minimize terminal usage.

### Phase 3: Faceplate Assembly
* **Install Hardware:** Insert the pre-wired switches and encoders through the mounting holes from the back of the front plate.
* **Tighten Fasteners:** Secure the components to the front plate using their included washers and hex nuts. Tighten firmly by hand, avoiding excessive torque on the plastic.
* **Attach Knobs:** Push the interface knobs onto the encoder shafts, aligning any internal flats with the shaft profiles.
* **Join Faceplate to Shell:** Align the completed front plate with the enclosure top. Secure them together using the designated M3 countersunk screws.

### Phase 4: Enclosure Integration

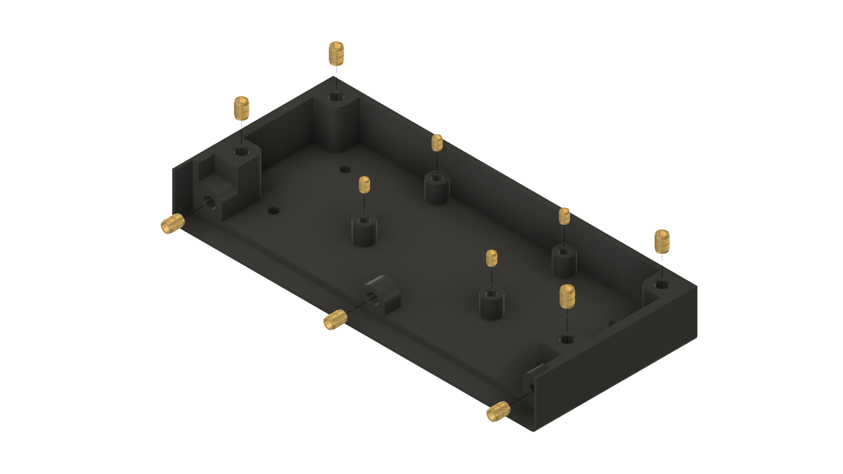
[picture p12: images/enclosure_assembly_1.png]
Enclosure bottom with heat-set inserts and standoff posts installed


* **Press in the Inserts:** Using a soldering iron (or a dedicated insert tool) heated to the
  insert manufacturer's recommended temperature, press the heat-set inserts squarely into the
  enclosure bottom's mounting posts. Do the same for the enclosure top: it isn't pictured
  separately, but takes the same inserts the same way.
* **Mount the Base Board:** Secure the completed breakout board sub-assembly into the enclosure
  bottom using the M3 pan-head screws.

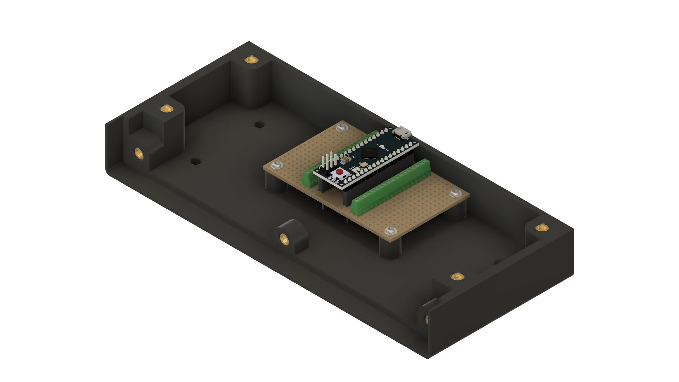
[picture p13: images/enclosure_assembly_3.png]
Breakout board sub-assembly mounted on standoffs in the enclosure bottom
  
* **Terminate Wires:** Route the front-plate wire bundles neatly through the case. Insert each individual signal wire into its designated screw terminal block port and lock down firmly.
* **Attach Mounting Plate:** Fix the mounting plate bracket to the rear of the enclosure bottom using the M4 × 6 mm socket-head screws.
* **Secure Case Shells:** Close the enclosure top and bottom halves together, ensuring no wires are pinched. Lock the shell with the M4 × 26 mm socket-head screws.

## Verification & First-Time Setup

1. **Check for shorts first (before plugging in USB):** use a multimeter to make sure none of your
   ground wires are accidentally touching a signal wire. This catches wiring mistakes before they
   reach your PC.
2. **Load the firmware:** follow the guide for your board: [Arduino Nano ESP32](../firmware/arduino_eps32_nano/README.md)
   or [Arduino Micro](../firmware/arduino_micro/README.md).
3. **Confirm the name:** once plugged in, the panel should show up as `Nobs Autopilot (Vendor: 303a
   Product: 80f4)`. If it shows a generic name instead, open Windows **Device Manager**, turn on
   **View → Show hidden devices**, uninstall any old listings for the board, and replug it.
4. **Bind it in the sim:** launch MSFS 2024, go to **Options → Control Options**, pick the
   **Nobs Autopilot** device, and assign your buttons to autopilot commands.

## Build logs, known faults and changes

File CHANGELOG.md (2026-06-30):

# Changelog

All notable changes to the Nobs Autopilot project (hardware, firmware, and documentation) are documented in this file.

The format is based on [Keep a Changelog](https://keepachangelog.com/en/1.1.0/),
and this project adheres to [Semantic Versioning](https://semver.org/spec/v2.0.0.html).

## [Unreleased]

### Added
- Initial project documentation in [README.md](README.md): VR design philosophy, hardware connection scheme, physical pinout reference, project cost estimate, and step-by-step assembly instructions.
- Arduino Micro firmware sketch ([firmware/arduino_micro/arduino_micro.ino](firmware/arduino_micro/arduino_micro.ino)) exposing 20 USB HID buttons (4 encoders × CW/CCW/push, plus 8 momentary switches) with full quadrature decoding, pulse-paced rotation steps, and host-configurable per-encoder acceleration over USB serial.
- Custom USB identity for the panel: VID `0x2341`, PID `0x0657`, product name "Nobs Autopilot".
- Firmware flashing and USB identity guide ([firmware/arduino_micro/README.md](firmware/arduino_micro/README.md)).
- Bill of Materials ([docs/bill-of-materials.md](docs/bill-of-materials.md)) and enclosure dimensions ([docs/dimensions.pdf](docs/dimensions.pdf)).
- 3D-printable enclosure models: top, bottom, front plate, and mounting plate ([models/](models/)).
- Wiring diagram and component library ([schematics/](schematics/)).
- MSFS 2024 autopilot control mapping template covering Heading, Altitude, Vertical Speed, and Airspeed.
- Bundled [Arduino Joystick Library](https://github.com/MHeironimus/ArduinoJoystickLibrary) (v2.1.1) used by the firmware.
- Placeholder for an ESP32 Nano firmware variant ([firmware/arduino_eps32_nano/](firmware/arduino_eps32_nano/)).
- Runtime-configurable USB identity for the Arduino Nano ESP32 build: PID and product name are stored in flash (NVS) and can be reassigned over USB serial with `SET_ID`/`GET_ID`, so each physical panel can be told apart by MSFS. Documented in [docs/board-identity.md](docs/board-identity.md).
- Arduino Micro pinout reference ([docs/arduino-micro-wiring.md](docs/arduino-micro-wiring.md)), split out now that the wiring docs are written around the Nano ESP32.
- Power/status LED on the Nano ESP32 build, wired to **D4** via a 120 Ω resistor: blinks while booting/waiting for USB enumeration, lights steady once the host PC has enumerated it.

### Changed
- The **Arduino Nano ESP32** is now the project's main board; the build instructions, BOM, and wiring docs are written around it, with the Arduino Micro documented as a supported alternative.
- Both firmware variants now report VID `0x303A` (Espressif's vendor ID) instead of `0x2341`, alongside PID `0x80F4` / "Nobs Autopilot".
- Corrected the BOM's USB cable spec to USB-C for the Nano ESP32 (was Micro-B, which only applies to the Arduino Micro alternative).
- Renamed `docs/Wiring diagram.pdf` to `docs/wiring-diagram.pdf` and linked it from the wiring and build-instructions docs.
- Split `docs/wiring-diagram.pdf` into separate per-board diagrams, `docs/wiring-diagram-esp32-nano.pdf` and `docs/wiring-diagram-micro.pdf`, and updated the wiring/build-instructions links to match.
- Moved the build instructions out of the README into their own guide ([docs/build-instructions.md](docs/build-instructions.md)), and added photos of the breakout board and enclosure integration steps ([images/](images/)).
- Restructured README.md to match the leaner style used by the other Nobs panel projects: a short intro, the VR design philosophy, a "Docs" link list, and a brief device-ID section, with the detailed wiring/firmware/cost content left to its own doc page.

### Removed
- The MSFS 2024 button-mapping template from the README (no replacement; it wasn't being kept up to date with the in-sim binding workflow).

[Unreleased]: https://github.com/ibovegar/nobs-fs-autopilot/commits/main

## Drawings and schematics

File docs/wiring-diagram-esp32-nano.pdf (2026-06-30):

# ENC1 ABCSW

SW1 123

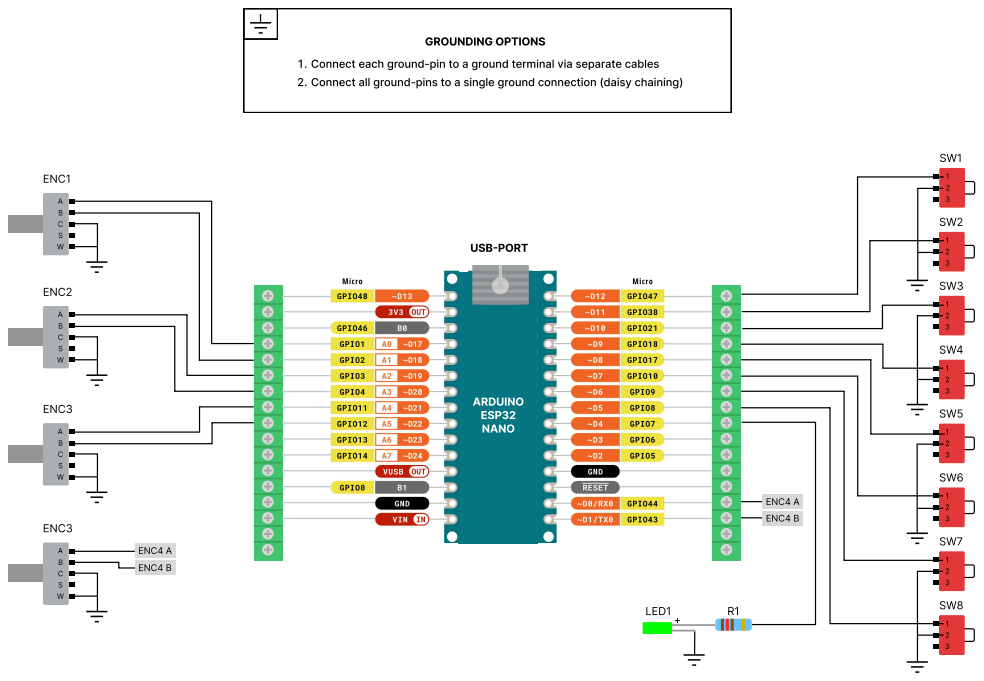
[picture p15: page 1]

Connect each ground-pin to a ground terminal via separate cables
Connect all ground-pins to a single ground connection (daisy chaining)

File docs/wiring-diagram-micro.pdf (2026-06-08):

SW1 123

SW2 123

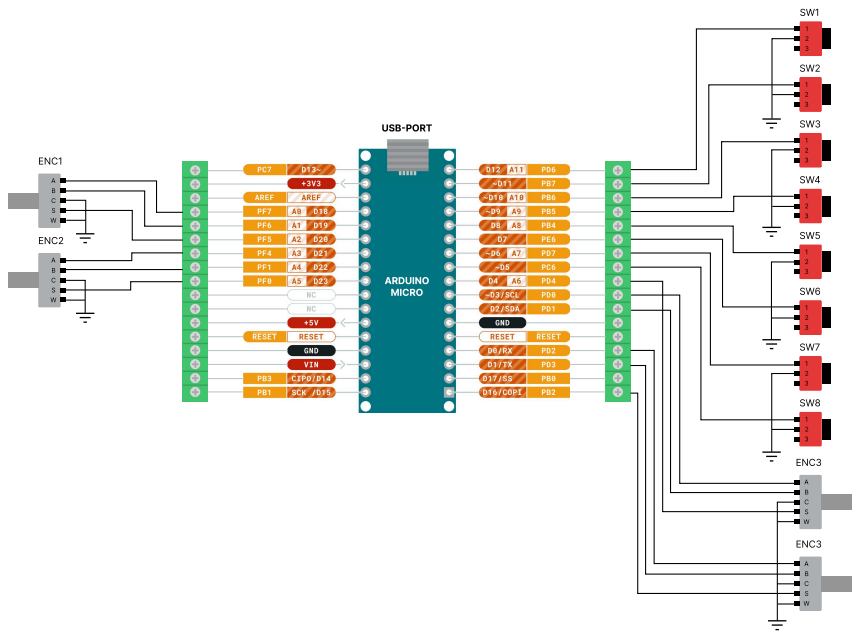
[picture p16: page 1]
ENC1 ABCSW; ENC2ABCSW; USB-PORT; ARDUINO MICRO; ENC3 ABCSW

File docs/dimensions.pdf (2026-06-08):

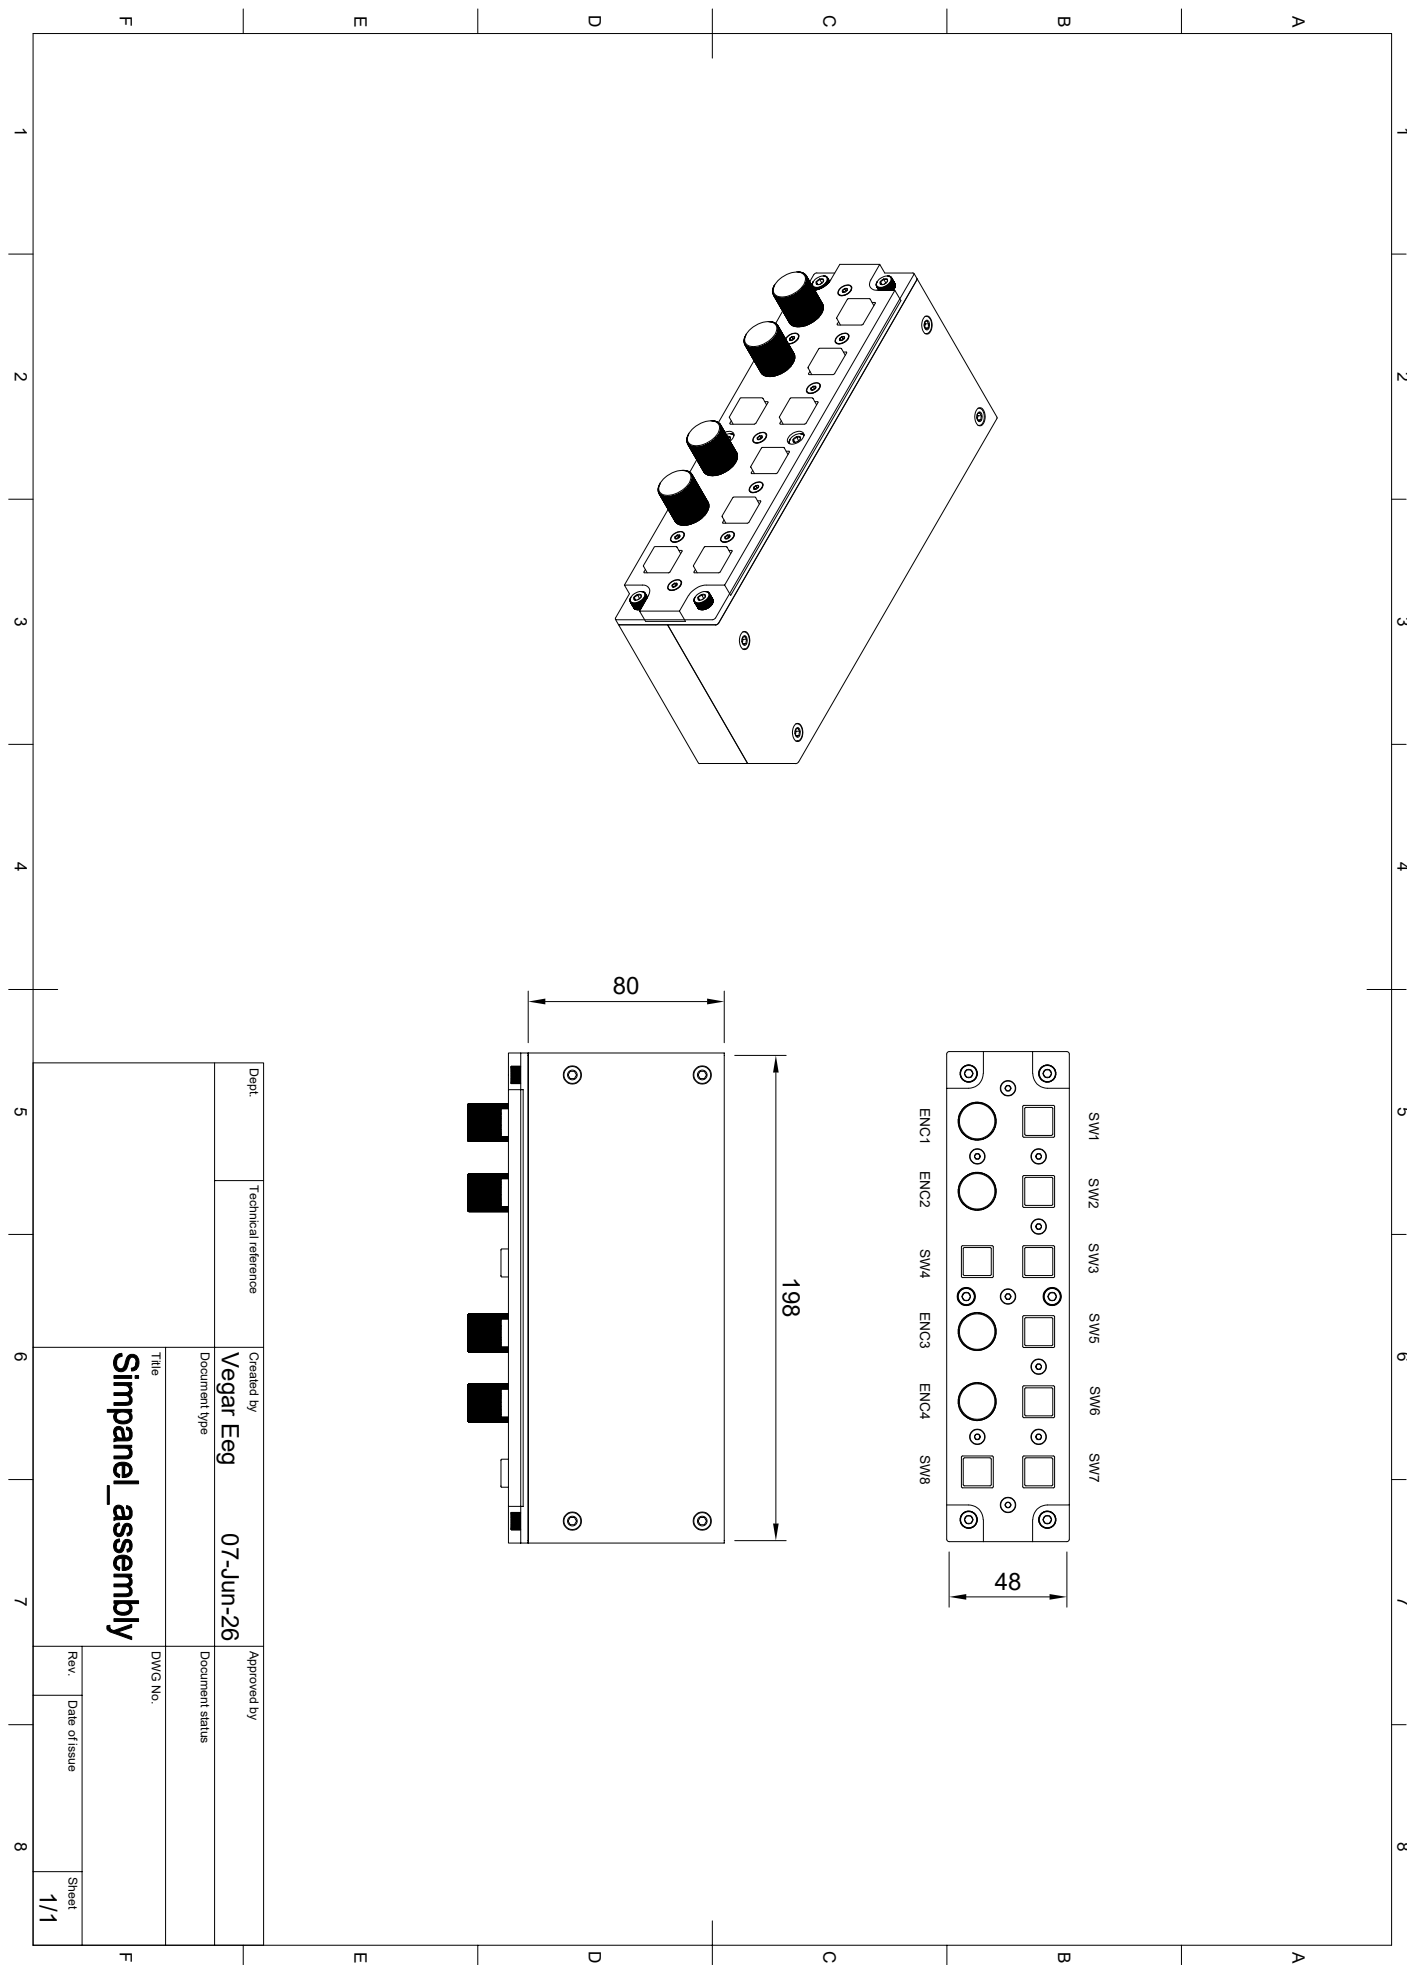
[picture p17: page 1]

1 A 2 3 4 5 6 7 8 1 2 3 4 5 6 7 8 FEDCB FEDCBA Dept. Technical reference Created by Approved by Title DWG No. Document type Document status Rev. Date of issue Sheet 07-Jun-26 1/1 Vegar Eeg SW1 SW2 SW3 SW8 SW7 SW6 SW5 ENC1 SW4 ENC2 ENC3 ENC4 198

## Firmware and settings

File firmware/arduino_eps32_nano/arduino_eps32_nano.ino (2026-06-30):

// Nobs Autopilot — Arduino Nano ESP32 (ESP32-S3) USB HID gamepad firmware.
//
// Functionally identical to the Arduino Micro build, ported to the ESP32-S3's
// native USB. Exposes 20 buttons in the exact order the nobs-fs app expects:
//   buttons  0..11  → 4 encoders × (CW, CCW, push)
//   buttons 12..19  → 8 standalone switches (SW1..SW8)
// See docs/arduino-esp-32-wiring.md for the full button + pin table.
//
// Host config: over the USB CDC serial port the app sets encoder acceleration
// sensitivity and can reassign the board's USB identity — see the serial protocol
// near handleSerialConfig().
//
// ── Arduino IDE Tools settings (required) ─────────────────────────────────────
//   Board:        "Arduino Nano ESP32"
//   USB Mode:     "Normal mode (TinyUSB)"    ← the default; needed for custom HID
//   Pin Numbers:  "By Arduino pin (default)"  so D0/A0… match the wiring doc
// No other Tools changes and NO edits to the installed Arduino core are needed — the
// whole USB-identity fix lives in this repo (this sketch + build_opt.h beside it).
//
// ── USB identity: dynamic, stored in NVS (Preferences) ────────────────────────
// The device enumerates with VID 0x303A (Espressif's vendor ID) and a PID + product
// name that are *configurable at runtime*. Each Nobs box gets its own PID so MSFS
// can't mirror/overwrite control bindings across panels. Out of the box this build
// defaults to PID 0x80F4 / "Nobs Autopilot" (matches the `autopilot` entry in the
// app's device registry, src/panel/panel.ts).
//
// The PID and name live in flash via the native Preferences library (NVS). On boot
// the firmware reads them *before* USB.begin() and applies them to the descriptor.
// The configuration app can change them over the USB CDC serial port (see the serial
// protocol below); after a change the firmware reboots so USB re-enumerates.
//
// That only works because the Nano ESP32 normally forces "USB CDC On Boot" and "DFU On
// Boot" on, which would make the core bring USB up at boot (before setup()), freezing
// the descriptor with the stock 0x2341/0x0070 identity. The build_opt.h file next to
// this sketch overrides both to 0 (it is appended to every compile, including the
// core's), so the boot-time USB.begin() is skipped and our runtime identity wins.
//
// Because "CDC On Boot" is then off, the core's `Serial` is the hardware UART — so the
// app's config port is our own USB CDC interface (the USBSerial object below).
//
// Re-flashing: the running firmware reports a custom PID (and, with DFU-on-boot off, no
// DFU runtime interface), so the IDE can't auto-enter the bootloader. Double-tap the
// RESET button (RGB LED pulses) before uploading. See this folder's README.md.

#include "USB.h"
#include "USBHID.h"
#include "USBCDC.h"
#include <EEPROM.h>
#include <Preferences.h>

#if ARDUINO_USB_MODE
#error "Set Tools > USB Mode to 'Normal mode (TinyUSB)'. Custom HID needs the TinyUSB stack."
#endif
#if ARDUINO_USB_CDC_ON_BOOT
#error "build_opt.h is not taking effect: ARDUINO_USB_CDC_ON_BOOT must be 0. Make sure build_opt.h sits next to this .ino (it disables CDC/DFU-on-boot so the runtime USB identity works)."
#endif

// ── Custom HID gamepad: 20 buttons, no axes ───────────────────────────────────
// The Micro used the ArduinoJoystickLibrary; here we declare an equivalent report
// descriptor (20 1-bit buttons + 4 bits of padding = a flat 3-byte report) and
// drive it through the ESP32 core's USBHID device interface.
static const uint8_t HID_REPORT_DESCRIPTOR[] = {
  0x05, 0x01,        // Usage Page (Generic Desktop)
  0x09, 0x05,        // Usage (Game Pad)
  0xA1, 0x01,        // Collection (Application)
  0x05, 0x09,        //   Usage Page (Button)
  0x19, 0x01,        //   Usage Minimum (Button 1)
  0x29, 0x14,        //   Usage Maximum (Button 20)
  0x15, 0x00,        //   Logical Minimum (0)
  0x25, 0x01,        //   Logical Maximum (1)
  0x75, 0x01,        //   Report Size (1)
  0x95, 0x14,        //   Report Count (20)
  0x81, 0x02,        //   Input (Data,Var,Abs)
  0x75, 0x01,        //   Report Size (1)
  0x95, 0x04,        //   Report Count (4)   — padding to a whole byte
  0x81, 0x03,        //   Input (Const,Var,Abs)
  0xC0               // End Collection
};

class NobsGamepad : public USBHIDDevice {
public:
  NobsGamepad() { HID.addDevice(this, sizeof(HID_REPORT_DESCRIPTOR)); }

  void begin() { HID.begin(); }

  // Set/clear one button bit in the pending report (mirrors Joystick.setButton).
  void setButton(uint8_t index, uint8_t value) {
    if (index >= 20) return;
    uint8_t byteIdx = index >> 3;
    uint8_t mask    = 1 << (index & 7);
    if (value) report[byteIdx] |= mask;
    else       report[byteIdx] &= ~mask;
  }

  // One USB report carrying every button change since the last call (mirrors
  // Joystick.sendState). Only transmitted when something actually changed — HID
  // hosts track button state edge-to-edge, so re-sending identical reports just
  // adds USB traffic and risks blocking the loop.
  void sendState() {
    if (memcmp(report, lastSent, sizeof(report)) == 0) return;
    if (HID.SendReport(0, report, sizeof(report))) {
      memcpy(lastSent, report, sizeof(report));
    }
  }

  // USBHIDDevice: hand the descriptor to the core during enumeration.
  uint16_t _onGetDescriptor(uint8_t* buffer) override {
    memcpy(buffer, HID_REPORT_DESCRIPTOR, sizeof(HID_REPORT_DESCRIPTOR));
    return sizeof(HID_REPORT_DESCRIPTOR);
  }

private:
  USBHID  HID;
  uint8_t report[3]   = { 0, 0, 0 };
  uint8_t lastSent[3] = { 0xFF, 0xFF, 0xFF }; // force the first real report out
};

NobsGamepad Joystick;

// USB CDC config port. With CDC-on-boot disabled (via build_opt.h) the core's `Serial`
// is the hardware UART, so we expose our own USB CDC interface for the app's Settings
// page. Like USBHID, USBCDC registers its interface in its constructor (static init),
// so it is in place before USB.begin() builds the composite descriptor in setup().
USBCDC USBSerial;

// ── Dynamic USB identity (NVS via Preferences) ────────────────────────────────
// VID is fixed (Espressif's vendor ID); PID + product name are stored in flash and
// host-configurable. Defaults are the autopilot profile; an unconfigured chip uses
// them. (Acceleration uses the emulated-EEPROM store below; identity uses its own
// Preferences namespace, so the two don't collide.)
// NB: named NOBS_USB_VID, not USB_VID — the core's pins_arduino.h #defines USB_VID.
const uint16_t NOBS_USB_VID  = 0x303A;
const uint16_t DEFAULT_PID   = 0x80F4;
const char*    DEFAULT_NAME  = "Nobs Autopilot";
const char*    NVS_NAMESPACE = "nobs";
const char*    NVS_KEY_PID   = "pid";
const char*    NVS_KEY_NAME  = "name";

Preferences prefs;
uint16_t     usbPid;  // active PID (kept alive for the whole session)
String       usbName; // active product name (c_str() must outlive USB.begin())

void loadIdentity() {
  prefs.begin(NVS_NAMESPACE, true); // read-only
  usbPid  = prefs.getUShort(NVS_KEY_PID, DEFAULT_PID);
  usbName = prefs.getString(NVS_KEY_NAME, DEFAULT_NAME);
  prefs.end();
}

void storeIdentity(uint16_t pid, const String& name) {
  prefs.begin(NVS_NAMESPACE, false); // read-write
  prefs.putUShort(NVS_KEY_PID, pid);
  prefs.putString(NVS_KEY_NAME, name);
  prefs.end();
}

// ── USB string descriptors: name the interfaces after the product ─────────────
// The core hardcodes the HID/CDC *interface* strings to "TinyUSB HID"/"TinyUSB CDC".
// For a composite device (HID + CDC) Windows and MSFS show that interface string as
// the controller's name — so without this it shows up as "TinyUSB HID" even though
// iProduct is "Nobs Autopilot". tud_descriptor_string_cb is weak in the core, so
// defining it here replaces it (no core edit needed) and points every interface
// string at the product name. Index map: 0=language, 1=manufacturer, 2=product,
// 3=serial (from the chip MAC, stable per board), 4+=interface strings → product.
extern "C" const uint16_t* tud_descriptor_string_cb(uint8_t index, uint16_t langid) {
  (void)langid;
  static uint16_t desc[40];

  if (index == 0) {
    desc[1] = 0x0409; // English (United States)
    desc[0] = (uint16_t)((3 << 8) | (2 * 1 + 2));
    return desc;
  }
  // Beyond our real strings (1..3 + a handful of interface strings). Returning NULL
  // mirrors the core and lets Windows' MS-OS probe at index 0xEE fail cleanly.
  if (index >= 16) return NULL;

  char serial[16];
  const char* str;
  switch (index) {
    case 1: str = "Arduino"; break;       // manufacturer (matches USB.manufacturerName)
    case 2: str = usbName.c_str(); break; // product (iProduct)
    case 3:                               // serial — stable per board
      snprintf(serial, sizeof(serial), "%012llX", (unsigned long long)ESP.getEfuseMac());
      str = serial;
      break;
    default: str = usbName.c_str(); break; // HID/CDC/config interface strings
  }

  uint8_t chr_count = strlen(str);
  if (chr_count > 38) chr_count = 38; // desc holds 39 UTF-16 chars + the header word
  for (uint8_t i = 0; i < chr_count; i++) desc[1 + i] = str[i];
  desc[0] = (uint16_t)((3 << 8) | (2 * chr_count + 2));
  return desc;
}

// ── Pin assignments (Arduino Nano ESP32 labels — see arduino-esp-32-wiring.md) ─
// Encoders: A/B quadrature pins + S push button. Encoder common (C) and the
// extra W pin are wired to GND.
//
// HEADS-UP: Encoder 1 Phase A is on D13, which on the Nano ESP32 is also the
// built-in amber LED (GPIO48 / LED_BUILTIN). INPUT_PULLUP holds it HIGH, so that LED
// stays lit whenever the firmware runs — expected, not a fault. The encoder still
// reads, but if you want the LED off (or cleaner readings), move Phase A to a free
// header pin (D2 is unused; D4 drives the status LED) and update the wiring doc to match.
const uint8_t encA[4]    = { D13, A2, A5, D0 };
const uint8_t encB[4]    = { A0,  A3, A6, D1 };
const uint8_t encPush[4] = { A1,  A4, A7, D3 };

// Standalone switches SW1..SW8 (pin 1 to the MCU, pin 2 to GND).
const uint8_t swPin[8]   = { D12, D11, D10, D9, D8, D7, D6, D5 };

// NOTE: every pin above is driven with INPUT_PULLUP, so the closed-to-GND wiring
// reads LOW = pressed. All of these GPIOs support the ESP32-S3 internal pull-up;
// if a future revision moves a signal onto a pull-up-less pad, add an external
// 10 kΩ pull-up to 3V3 there.

// ── Status LED (D4) ────────────────────────────────────────────────────────────
// Blinks while booting/waiting for USB enumeration, steady once enumerated. D4 also
// doubles as DSR (a USB CDC modem-control signal), but this sketch never drives DSR,
// so the pin is free for plain GPIO use.
const uint8_t STATUS_LED_PIN = D4;

// ── Button index map (must match the wiring doc / src/panel/panel.ts) ─────────
const uint8_t encBase[4] = { 0, 3, 6, 9 }; // CW = base, CCW = base + 1, push = base + 2
const uint8_t swBase     = 12;

// ── Encoder rotation state ────────────────────────────────────────────────────
// Full quadrature decode: every loop read both A and B and accumulate only valid
// Gray-code transitions. Sampling B at a single A edge mis-read direction (CCW
// triggered false CW); here a bounce that jumps two bits, or wiggles back and
// forth, nets to zero — no false steps in either direction, and it doesn't care
// where the detent rests. One detent = one full cycle = 4 counts, so we emit a
// CW/CCW step each time the accumulator crosses ±DETENT_STEPS.
//
// Each detent becomes one or more momentary CW/CCW presses, *queued* rather than
// held: a held-and-re-armed button (the old approach) merged into one long press
// when you spun fast, so rapid rotation lost counts. The generator emits each
// queued press as a pulse (PULSE_ON_MS) + forced low gap (PULSE_GAP_MS) so each
// one is counted as a distinct press.
//
// Pulse length is sized for MSFS, NOT the web app. The app reads every ~1 ms USB
// report, so it counts even 2 ms pulses — but MSFS only samples gamepad state
// about once per frame (~16–33 ms). A pulse shorter than a frame can begin and end
// between two MSFS samples and never register, which is why fast spins moved the
// heading bug barely or not at all. To make MSFS see each press we hold it (and the
// gap after it) for about one frame at 60 fps (~16 ms), capping the emit rate at
// ~1000/(ON+GAP) ≈ 33 presses/s — the practical ceiling, since MSFS counts each
// press as 1° so max heading-bug rate ≈ that many °/s. If the sim runs below 60 fps
// (or stutters), a press can again fall between samples; bump ON/GAP back toward 20
// ms if steps go missing. The queue clamp is small so a fast flick's tail drains in
// ~0.25 s, not seconds.
const int8_t        DETENT_STEPS   = 4;  // quadrature counts per detent
const unsigned long PULSE_ON_MS    = 15; // CW/CCW button held high per press (~1 MSFS frame @ 60 fps)
const unsigned long PULSE_GAP_MS   = 15; // forced low gap between presses (~1 MSFS frame @ 60 fps)
const int8_t        STEP_QUEUE_MAX = 8;  // clamp pending steps (bounds post-spin tail to ~0.25 s)

// Rotational acceleration: presses emitted per detent grow with spin speed (the
// time since the previous detent on that encoder). A slow, deliberate turn stays
// 1:1 for single-unit precision; a fast flick multiplies, so e.g. the MSFS heading
// bug races instead of crawling 1° per detent. Tune the thresholds/multipliers to
// taste. Kept within the emit ceiling so the queue (and its tail) stays small.
const unsigned long ACCEL_T1 = 80; // ms between detents; slower than this → ×1
const unsigned long ACCEL_T2 = 40; // ms
const unsigned long ACCEL_T3 = 20; // ms; faster than this → fastest multiplier
const int8_t        ACCEL_M1 = 2;  // ACCEL_T2..ACCEL_T1 ms apart
const int8_t        ACCEL_M2 = 5;  // ACCEL_T3..ACCEL_T2 ms apart
const int8_t        ACCEL_M3 = 10; // faster than ACCEL_T3 (fast flick)

// Acceleration sensitivity (0..255), *per encoder*, host-configurable and saved in
// emulated EEPROM (flash). It scales the *extra* presses from the curve above: 0 =
// acceleration off (always 1:1), 255 = the full ACCEL_M* multipliers. Each encoder
// i uses EEPROM byte EEPROM_ADDR_ACCEL + i; an uninitialised byte reads 0xFF (=255),
// so the out-of-box default is full acceleration on every knob.
const int     EEPROM_SIZE       = 8;
const int     EEPROM_ADDR_ACCEL = 0;
uint8_t       accelSens[4] = { 255, 255, 255, 255 };

// ESP32's EEPROM is emulated in flash: writes are buffered until commit(). Mirror
// the AVR EEPROM.update() — only touch flash when the value actually changes.
void eepromUpdate(int addr, uint8_t value) {
  if (EEPROM.read(addr) != value) {
    EEPROM.write(addr, value);
    EEPROM.commit();
  }
}

// Direction of each (prevAB << 2 | currAB) transition: +1 CW, -1 CCW, 0 none/invalid.
// Derived from the confirmed orientation: A-falling-with-B-high (11→01) is CW.
const int8_t qdec[16] = {
   0, -1,  1,  0,
   1,  0,  0, -1,
  -1,  0,  0,  1,
   0,  1, -1,  0,
};

uint8_t       prevAB[4];     // last (A<<1 | B) phase per encoder
int8_t        accum[4];      // accumulated quadrature counts toward a detent
int8_t        pending[4];    // queued steps not yet pulsed (signed: + CW, − CCW)
unsigned long lastStepMs[4]; // millis() of the previous detent (for acceleration)
bool          pulseOn[4];    // is a CW/CCW press currently asserted?
int           pulseBtn[4];   // which button that press is on
unsigned long phaseUntil[4]; // millis() when the current on/gap phase ends

// ── Host serial config ───────────────────────────────────────────────────────
// Line protocol over the USB CDC port (the app's Settings page).
//
// Acceleration — each encoder has its own sensitivity, addressed by a single-digit
// index i (0..3):
//   "A<i><n>\n"  set encoder i sensitivity to n (0..255), persisted to EEPROM
//   "A<i>?\n"    query encoder i sensitivity
// Either way we reply "A<i>=<n>\n" so the host can confirm/read the stored value.
//
// Identity — reassign the board's USB PID + product name (persisted to NVS):
//   "SET_ID:<pidHex>:<name>\n"  store PID (hex, e.g. 80F4) + name, then soft-reboot
//                               so the new identity takes effect; replies "OK:<pid>:<name>"
//   "GET_ID\n"                  reply "ID:<pidHex>:<name>" with the stored values
char    cmdBuf[64];
uint8_t cmdLen = 0;

void applyAccelCommand(const char* s) {
  if (s[0] != 'A') return;
  uint8_t i = s[1] - '0';
  if (i >= 4) return;          // need a valid encoder index (0..3)
  const char* rest = s + 2;    // value or '?' follows the index
  if (rest[0] != '?' && rest[0] != '\0') {
    long v = atol(rest);
    if (v < 0) v = 0;
    else if (v > 255) v = 255;
    accelSens[i] = (uint8_t)v;
    eepromUpdate(EEPROM_ADDR_ACCEL + i, accelSens[i]); // only writes if changed
  }
  USBSerial.print('A');
  USBSerial.print(i);
  USBSerial.print('=');
  USBSerial.println(accelSens[i]);
}

void printIdentity(const char* prefix) {
  char pidHex[5];
  snprintf(pidHex, sizeof(pidHex), "%04X", usbPid);
  USBSerial.print(prefix);
  USBSerial.print(':');
  USBSerial.print(pidHex);
  USBSerial.print(':');
  USBSerial.println(usbName);
}

void applyIdCommand(const char* s) {
  if (strcmp(s, "GET_ID") == 0) {
    printIdentity("ID");
    return;
  }
  if (strncmp(s, "SET_ID:", 7) != 0) return;

  const char* p     = s + 7;          // "<pidHex>:<name>"
  const char* colon = strchr(p, ':');
  if (!colon || colon == p) return;   // need a PID and a separator

  char pidStr[8] = { 0 };
  size_t n = colon - p;
  if (n >= sizeof(pidStr)) return;
  memcpy(pidStr, p, n);
  uint16_t pid = (uint16_t)strtol(pidStr, nullptr, 16);

  String name = colon + 1;            // everything after the second ':'
  name.trim();
  if (name.length() == 0) return;

  storeIdentity(pid, name);
  usbPid  = pid;                       // reflect the just-stored values
  usbName = name;
  printIdentity("OK");
  USBSerial.flush();
  delay(50);                           // let the CDC packet drain before reset
  ESP.restart();
}

void applyConfigCommand(const char* s) {
  if (strncmp(s, "SET_ID:", 7) == 0 || strcmp(s, "GET_ID") == 0) applyIdCommand(s);
  else applyAccelCommand(s);
}

void handleSerialConfig() {
  while (USBSerial.available()) {
    char c = USBSerial.read();
    if (c == '\n' || c == '\r') {
      cmdBuf[cmdLen] = '\0';
      if (cmdLen > 0) applyConfigCommand(cmdBuf);
      cmdLen = 0;
    } else if (cmdLen < sizeof(cmdBuf) - 1) {
      cmdBuf[cmdLen++] = c;
    } else {
      cmdLen = 0; // overlong line (no newline) — drop it and resync
    }
  }
}
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
void loop() {
  unsigned long now = millis();

  handleSerialConfig(); // apply any pending acceleration-sensitivity command
  updateStatusLed();    // blink while waiting for USB enumeration, steady once enumerated

  // ── Encoders ────────────────────────────────────────────────────────────────
  for (uint8_t i = 0; i < 4; i++) {
    // Accumulate valid quadrature transitions; emit a step each full detent.
    uint8_t ab = (digitalRead(encA[i]) << 1) | digitalRead(encB[i]);
    if (ab != prevAB[i]) {
      accum[i] += qdec[(prevAB[i] << 2) | ab];
      prevAB[i] = ab;

      int8_t dir = 0;
      if (accum[i] >= DETENT_STEPS) {
        dir = 1;            // clockwise  → CW
        accum[i] -= DETENT_STEPS;
      } else if (accum[i] <= -DETENT_STEPS) {
        dir = -1;           // counter-cw → CCW
        accum[i] += DETENT_STEPS;
      }

      if (dir != 0) {
        // Acceleration: scale presses-per-detent by how fast we're turning, then
        // by the host-set sensitivity (0 = off/1:1, 255 = full curve).
        unsigned long delta = now - lastStepMs[i];
        lastStepMs[i] = now;
        int8_t baseMult = (delta < ACCEL_T3) ? ACCEL_M3
                        : (delta < ACCEL_T2) ? ACCEL_M2
                        : (delta < ACCEL_T1) ? ACCEL_M1
                        : 1;
        int16_t mult = 1 + ((int16_t)(baseMult - 1) * accelSens[i]) / 255;
        // Queue the (scaled) steps, clamped; the generator below paces them out.
        int16_t want = pending[i] + (int16_t)dir * mult;
        if (want > STEP_QUEUE_MAX) want = STEP_QUEUE_MAX;
        else if (want < -STEP_QUEUE_MAX) want = -STEP_QUEUE_MAX;
        pending[i] = (int8_t)want;
      }
    }

    // Pulse generator: turn queued steps into distinct press/gap cycles so even
    // rapid rotation counts every detent.
    if (pulseOn[i]) {
      if (now >= phaseUntil[i]) {           // end the press → start the low gap
        Joystick.setButton(pulseBtn[i], 0);
        pulseOn[i] = false;
        phaseUntil[i] = now + PULSE_GAP_MS;
      }
    } else if (now >= phaseUntil[i] && pending[i] != 0) {
      int8_t dir = (pending[i] > 0) ? 1 : -1; // start the next queued press
      pending[i] -= dir;
      pulseBtn[i] = (dir > 0) ? encBase[i] : encBase[i] + 1;
      Joystick.setButton(pulseBtn[i], 1);
      pulseOn[i] = true;
      phaseUntil[i] = now + PULSE_ON_MS;
    }

    // Push button is reported as a held level (pressed = LOW with INPUT_PULLUP).
    Joystick.setButton(encBase[i] + 2, digitalRead(encPush[i]) == LOW ? 1 : 0);
  }

  // ── Standalone switches ───────────────────────────────────────────────────────
  for (uint8_t i = 0; i < 8; i++) {
    Joystick.setButton(swBase + i, digitalRead(swPin[i]) == LOW ? 1 : 0);
  }

  // One USB report per loop with all the updates above (sent only when changed).
  Joystick.sendState();
}

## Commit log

2026-06-01 Add models
    [Enclosure_bottom.step, Enclosure_top.step, Front_plate.step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]
2026-06-08 Add firmware, schematics, docs, and relicense to AGPL-3.0
2026-06-09 Add Arduino Nano ESP32 firmware and rework docs for DIY builders
    Firmware:
    - Add Nano ESP32 (ESP32-S3) firmware: 20-button HID gamepad + USB CDC
    config port, same 2341:0657 "Nobs Autopilot" identity as the Micro build
    - Set the USB identity at runtime, enabled by a repo-local build_opt.h, so
    no edits to the installed Arduino core are required
    Docs:
    - Add the Nano ESP32 wiring map (docs/arduino-esp-32-wiring.md)
    - Move both firmware guides into their firmware/ folders as README.md
    - Rewrite the guides and soften the README/BOM into plain, beginner-friendly
    language for the DIY community
    - Surface the Nano ESP32 as an alternative board throughout the README
    Misc:
    - Move the wiring diag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
    [arduino_eps32_nano.ino]
2026-06-13 Update models
    [Enclosure_bottom.step, Enclosure_top.step, Front_plate.step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]
2026-06-18 Fix heat insert issue
    [Enclosure_bottom.step, Enclosure_top.step]
2026-06-18 Rename models
    [Enclosure_bottom.step, Enclosure_top.step]
2026-06-18 Rename them for real this time!
    [enclosure_bottom.step, enclosure_top.step]
2026-06-21 Make Arduino Nano ESP32 the main board
    Rewrite docs and firmware around the Nano ESP32 as the primary build, with
    the Arduino Micro as a documented alternative: shared VID 0x303A across
    both firmware variants, runtime-configurable USB PID/name over serial for
    the ESP32 build, a split-out Arduino Micro wiring reference, a corrected
    BOM USB cable spec, and a renamed wiring diagram.
    [arduino_eps32_nano.ino]
2026-06-21 Move build instructions to docs/ and rewrite assembly steps to match photos
    Split the build instructions out of the README into docs/build-instructions.md,
    and rewrite the Assembly Instructions section to describe the actual
    heat-set-insert/direct-mount build shown in the new assembly photos, replacing
    the outdated stripboard/terminal-block steps.
2026-06-22 Restore breakout-board assembly steps and simplify the README
    The new assembly photos show the actual build uses a stripboard breakout
    board (headers + terminal blocks, same layout for either Arduino board)
    mounted into the enclosure on standoffs -- correcting the previous rewrite,
    which had wrongly replaced that process with a direct-mount description.
    Restore the original Phase 1-4 steps and attach the new photos to the
    breakout-board and enclosure-integration stages.
    Also add the BOM's project cost estimate and rework README.md into a
    leaner structure (short intro, design philosophy, a Docs link list, and a
    brief device-ID section) matching the other Nobs panel projects, dropping
    the MSF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
2026-06-28 Update frontplate model
    [nobs_autopilot_frontpanel.step]
2026-06-30 Add power/status LED and resistor to the BOM
    Adds a 3mm green LED (Lumex SSL-LX30FT4GD) and a 120 ohm current-limiting
    resistor (KOA Speer MFS1/4DCT52R1200F) for the panel's power/status
    indicator.
2026-06-30 Add status LED firmware and split the wiring diagram per board
    Drive the D4 status LED (added to the BOM/wiring docs) from USB
    enumeration state: blinks while booting/waiting for the host, steady once
    enumerated. Also split the single wiring-diagram.pdf into
    wiring-diagram-esp32-nano.pdf and wiring-diagram-micro.pdf, one per board,
    and repoint the wiring/build-instructions links at the right one.
2026-07-01 Add product image and wiring diagram links to README
2026-07-02 Document rig mounting layout and add assembly image
    Shows how Nobs Panel, Approach, and Autopilot mount together on a
    T-slot rig around the central yoke/wheel assembly.
2026-09-07 Status LED timeout, export models as STL, ignore 3mf files
    - Status LED on the Nano ESP32 build now gives up blinking and goes
    dark after 10s if no USB host ever enumerates it (e.g. powered from
    a charger with no data lines), instead of blinking indefinitely.
    The wait window restarts if the host later disconnects.
    - Swap the enclosure/mounting/frontpanel models from STEP to STL.
    - Ignore *.3mf slicer project files (large, regenerable from source
    models).
2026-11-02 Add wiring diagram as SVG and HTML
    The same pins and layout as the existing wiring doc, drawn with each
    control beside the header pins it connects to. The SVG is on a white
    background; the HTML page follows the light/dark theme.
2026-11-02 Force a clean USB hand-over on a cold plug-in
    At power-up the ESP32-S3 first shows up as its built-in USB JTAG/serial
    device (303A:1001). If the host never sees it drop off the bus, it never
    enumerates the Nobs device. Drop the D+ pull-up for 250 ms before
    USB.begin() so the host registers a real disconnect first.
